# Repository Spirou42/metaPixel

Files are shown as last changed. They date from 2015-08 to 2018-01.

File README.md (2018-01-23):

# metaPixel
**A colourful open source art project.**

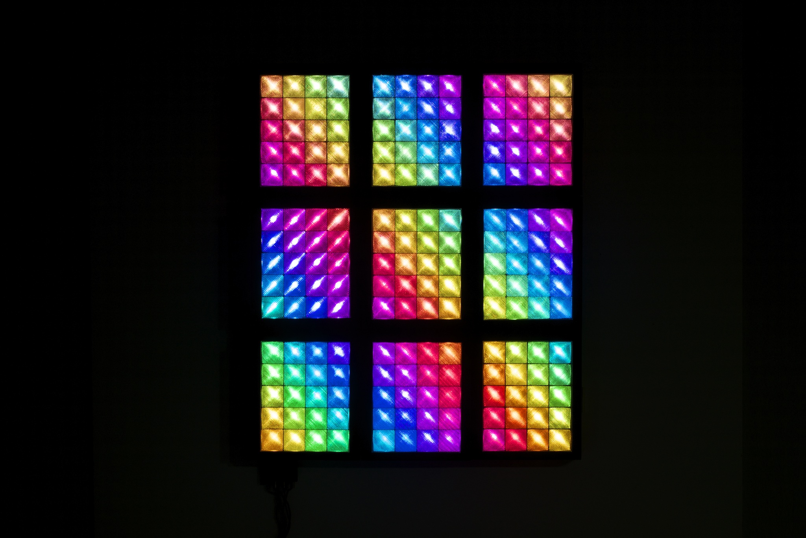
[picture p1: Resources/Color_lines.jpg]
Plasma Image


## Description
metaPixel is a (mostly) 3D printed, modular, extendable, magnetic pixel display for showing "retro" animations well known from the *good old days*™.

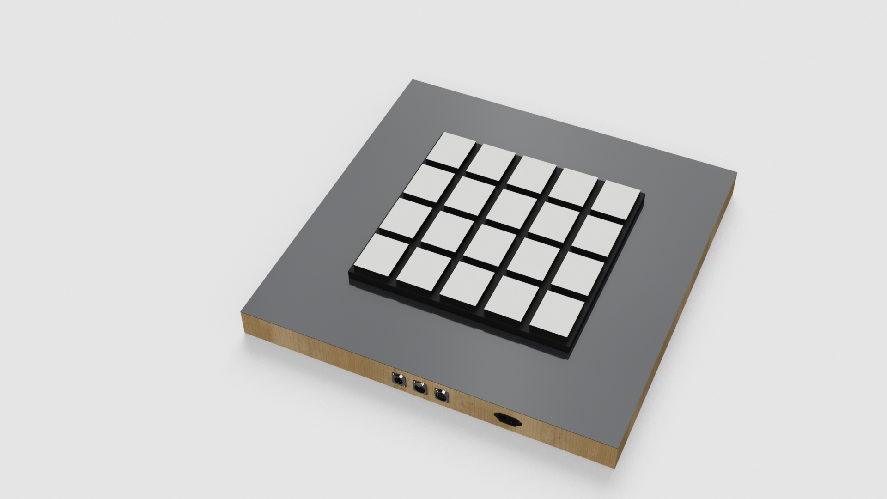
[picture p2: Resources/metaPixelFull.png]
metaPixel Design

The whole design uses a lot of magnets for adding strength to inter module connections, to hold the module cover and diffusors in place or to stick the modules onto the steel base.

The metaPixel display consists of 4 main parts:

1. steel plate
2. 20 metaPixel modules
3. controller and power supply 
4. Frame with connectors 

### Steel plate
The central structure of the whole installation is a 700 x 700 x 0.5 mm sheet of black painted steel. Both, the display modules as well as the controller and the power supply are attached with magnets to both sides of the plate.

### Frame
The steel plate is mounted to a wood frame with 20 ring magnets. 
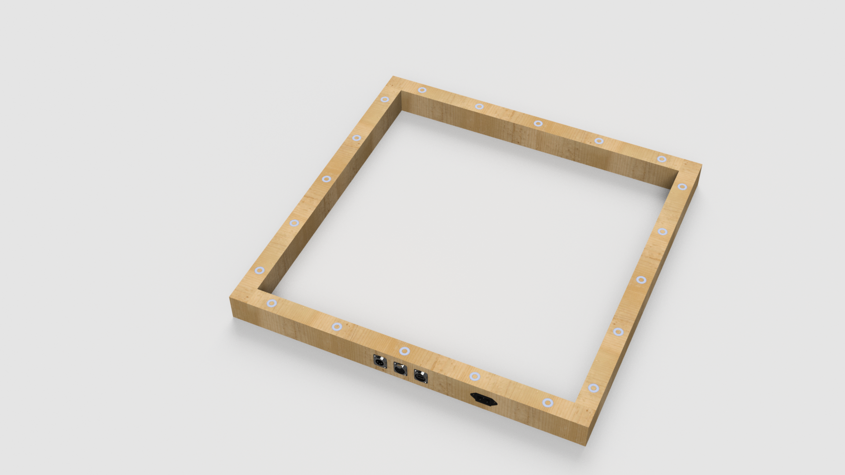
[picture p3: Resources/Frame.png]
Frame


The wood frame contains cut outs for a standard power connector as well as for DMX (3 pin XLR) and USB connectors. 
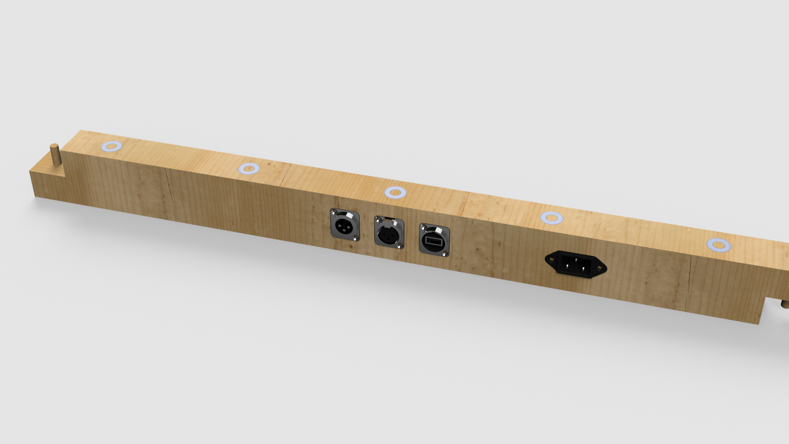
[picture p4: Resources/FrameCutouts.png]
CutOuts


### metaPixel Module
Each module contain 20 "intelligent" RGB LEDs in a 4 by 5 grid on a small printed carrier board.
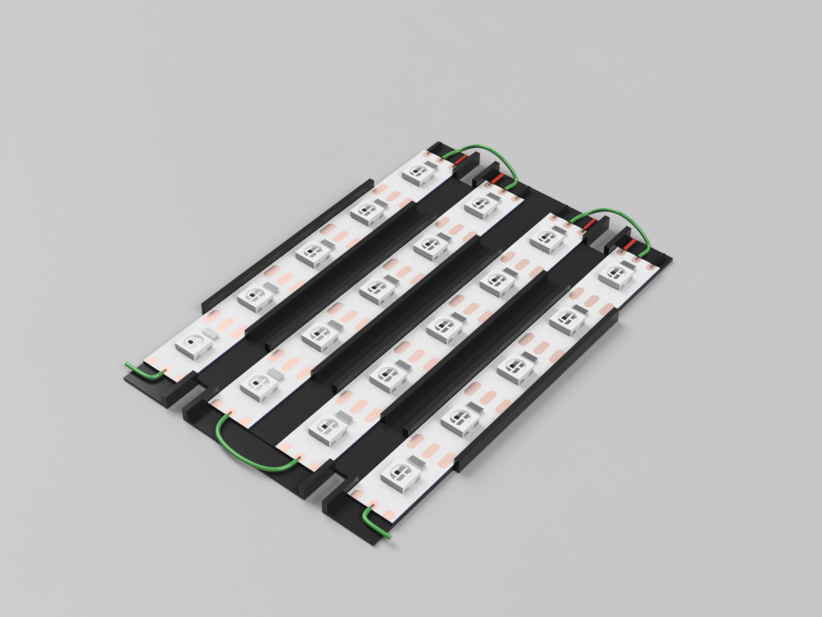
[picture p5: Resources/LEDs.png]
LED Stripes
 

The modules interconnect via a 3 pin connector. While the power connections goes straight from the input to the output with taps for each LED stripe. The data signal is routed on a zigzag path trough the stripes.
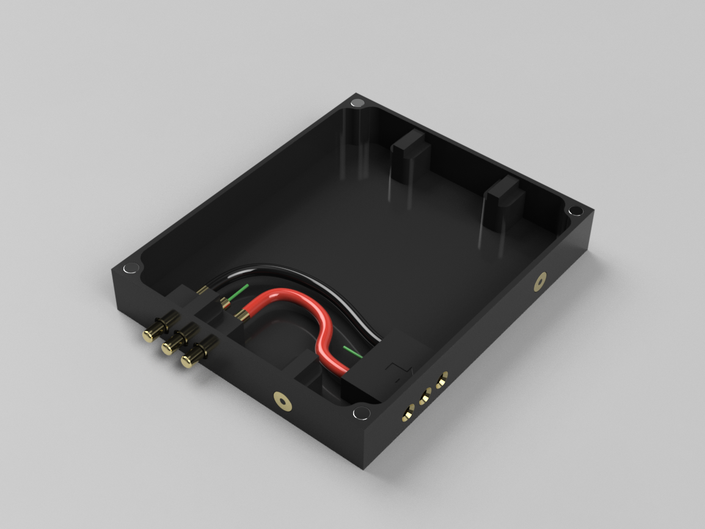
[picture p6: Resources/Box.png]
metaPixel Box


The LED carrier rests on top of four pillars which also contain some of the magnets.
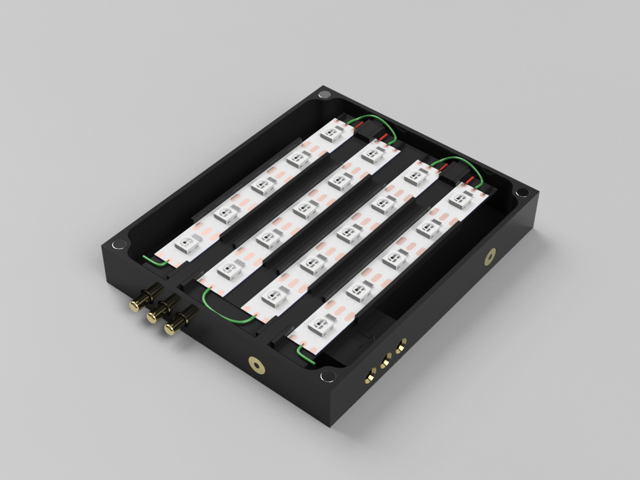
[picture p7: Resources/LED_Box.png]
metaPixel Box with LEDs


Four magnets in the corners of the box holds the cover and grid in place.
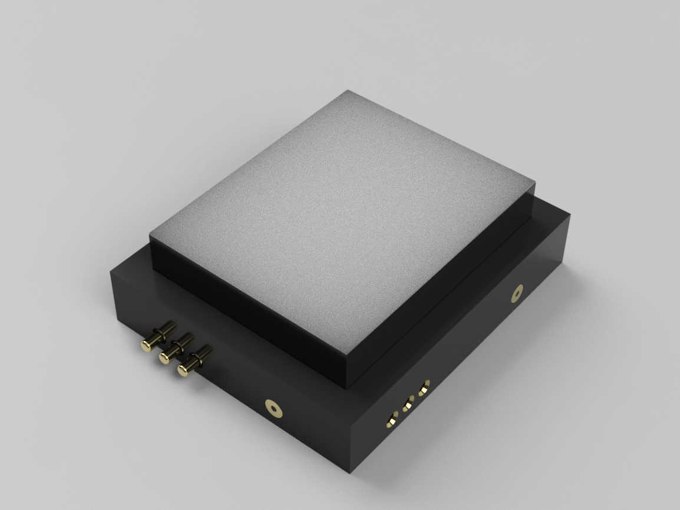
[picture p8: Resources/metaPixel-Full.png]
metaPixelWholeBox


[plasmaStripes]: Resources/Color_lines.jpg "Plasma Stripes"
[ledStripes]: Resources/LEDs.png "LED-Base"
[metaPixelBox]: Resources/Box.png "megaPixel box with connectors"
[metaPixelLedBox]: Resources/LED_BOX.png "box with LED carrier"
[metaPixelFrame]: Resources/Frame.png "Frame with connectors and magnets"
[metaPixelFrameCutOuts]: Resources/FrameCutouts.png "Frame connectors"
[metaPixelAll]: Resources/metaPixelFull.png "metaPixel Display"
[metaPixelWholeBox]: Resources/metaPixel-Full.png "a full rendered metaPixel module"
[allParts]: Resources/Components.jpg "Photo of all parts of a metaPixel"

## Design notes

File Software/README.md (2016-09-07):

#Software
Here, you'll find a basic description on how the metaPixel Software can be build and how the Software works.

## Building
The metaPixel Software uses the Arduino build environment, Teensyduino to add Teensy 3.1 support and a couple of third party libraries.

### Tools
1. [Arduino](https://www.arduino.cc/en/Main/Software) environment
2. [Teensyduino](http://www.pjrc.com/teensy/teensyduino.html)

### Libraries
1. [my version](https://github.com/Spirou42/AVRQueue) of [AVRQueue](https://github.com/Zuph/AVRQueue)  
a simple task switching library. metaPixel uses this library to implement all concurrent tasks like Backbuffer blending, Effect rendering and command execution.
2. [my version](https://github.com/Spirou42/ILI9341_t3) of [ILI9341_3](https://github.com/PaulStoffregen/ILI9341_t3) 
3. [Streaming](http://arduiniana.org/libraries/streaming/)  
C++ Stream operators for the Arduino serial class. Simply because it is easier to read and type than Arduinos `println`
4. [FastLED](http://fastled.io)  actually you have to use [my Version of FastLED](https://github.com/Spirou42/FastLED)
LED Driver Library. FastLED is a very neat LED handling library with a lot of well designed features. It supports different type of 'intelligent' LEDs and LED controllers, provides a lot of fast fixed point arithmetic and support RGB as well as HSV color space.     

## Overview
`metaPixel.h` and `metaPixel.ino` are the main files of the metaPixel controller software. `metaPixel.h` contains all definitions, prototypes, defines and includes.

###Files
* **Commands**
Serial line receiver and parser, commands, command queue and interpreter

* **Effect**
Base class for all Effects.  

* **Effect...**
The Effects itself  

* **metaDisplay**
The main class for handling the LED display. This class responsible for all display related activities like colouring pixels, drawing lines a.s.o.. In addition the `metaDisplay` class ist

* **metaModule**
A coordinate mapper for a single module used by `metaDisplay` to map `(x,y)` coordinates to a frame buffer index.

* **Palettes**
A couple of Palette definitions extracted with FastLEDs [PaletteKnife](http://fastled.io/tools/paletteknife/) tool from [cpt-city](http://soliton.vm.bytemark.co.uk/pub/cpt-city/)

* **Parameter**
A couple of interrupt changeable, animatable `int16_t` values. This class provides the basic infrastructure for managing and mapping parameters.

* **Types**
The content of this file will move to different places in the future. Actually it contains bunch of structure and type definitions.

* **VT100Stream**
Some extensions for streaming VT100 control chars.

## Controlling the Display

metaPixel is a simple state machine controlled by a couple of `int16_t` values encapsulated into a `Parameter16_t` class providing simple animation capabilities.

Fifteen `Parameter16_t` values are actually implemented and used to control global and effect local functions.

<table>
<tr><th>Index</th><th>Parameter Name</th><th>Range</th><th>Description</th></tr>
<tr><th colspan='4' align='left'>System Parameter</th></tr>
<tr><td align="center">0</td><td align="center">P</td><td align="center">0 - 6</td><td>Effect Program</td></tr>
<tr><td align="center">1</td><td align="center">D</td><td align="center">1 - 5000</td><td>Effect Frame Delay</td></tr>
<tr><td align="center">2</td><td align="center">C</td><td align="center">0 - 11</td><td>Palette</td></tr>
<tr><td align="center">3</td><td align="center">B</td><td align="center">0 - 255</td><td>LED Brightness</td></tr>
<tr><td align="center">4</td><td align="center">Q</td><td align="center">0 - 5</td><td>Mirror Mode</td></tr>
<tr><td align="center">5</td><td align="center">Z</td><td align="center">1 - 14</td><td>Blend factor</td></tr>
<tr><td align="center">6</td><td align="center">A</td><td align="center">0 - 1</td><td>Display Resoultion</td></tr>
<tr><th colspan='4' align='left'>Effect Parameter</th></tr>
<tr><td align="center">7</td> <td align="center">U</td><td align="center">-</td><td>Effect Speed 1</td></tr>
<tr><td align="center">8</td> <td align="center">V</td><td align="center">-</td><td>Effect Speed 1</td></tr>
<tr><td align="center">9</td> <td align="center">R</td><td align="center">-</td><td>Effect Scale 1</td></tr>
<tr><td align="center">10</td><td align="center">I</td><td align="center">-</td><td>Effect Scale 2</td></tr>
<tr><td align="center">11</td><td align="center">O</td><td align="center">-</td><td>Effect Parameter 1</td></tr>
<tr><td align="center">12</td><td align="center">H</td><td align="center">-</td><td>Effect Parameter 1</td></tr>
<tr><td align="center">13</td><td align="center">M</td><td align="center">0 - 255</td><td>Effect Mask 1</td></tr>
<tr><td align="center">14</td><td align="center">N</td><td align="center">0 - 255</td><td>Effect Mask 2</td></tr>
</table>

### Serial Interface
The metaPixel display is controlled by a simple serial command line interface. Connect your computer to the USB-Serial with a VT100 capable terminal program and press `Return`

	Effect: Noise
	Parameter:
	nScale    [R] 35 (255)        nSpeed    [U]*5 (255)         hSpeed    [V] 253 (255)
	nMask     [M] 1 (7)

	Program   [P] 1 (6)           Delay     [D] 100 (5000)      Palette   [C] 8 (11)
	Bright    [B] 160 (255)       Mirror    [Q] 0 (5)           Fade      [Z] 3 (14)
	Res       [A] 1 (1)

	>

From top to bottom you'll see:
* the name of the currently running Effect
* the effect parameters
* the system parameters

Each parameter entry consist of 5 parts
1. Descriptive Name
2. Parameter Name in `[]`
3. current value
4. optional animation marker `*`
5. current max value in `()`

To change a value simply type the parameter name followed by the new value. For example sending `P5` or `p5` will change the current effect to **Fire**
You can combine as many value changes in a single line as you wish as long as the line length did not exceed 512 bytes.

#### Additional Commands
In addition setting a single value to a effect parameter there is a couple of 'control' commands implemented.

<table>
<tr><th>Function</th><th>Command</th><th>Format</th></tr>
<tr><td>Bounce</td><td>~</td><td>~[paraName][startValue] [endValue] [time]</td></tr>
<tr><td colspan=2></td><td >Bounces the value of [paraName] between [startValue] and [endValue] in [time] sec.</td></tr>
<tr><td>Animate</td><td>@</td><td>@[paraName][startValue] [endValue] [time]</td></tr>
<tr><td colspan=2></td><td>Animates the value of [paraName] from [startValue] to [endValue] in [time] sec.</td></tr>
<tr><td>Stop Animate</td><td>*</td><td>*[paraName]</td></tr>
<tr><td colspan=2></td><td>Stops any animation on parameter [paraName]</td></tr>
<tr><td>Wait</td><td>&</td><td>&[time]</td></tr>
<tr><td colspan=2></td><td>Stops command processing for [time] sec.</td></tr>
<tr><td>Wait for Animation</td><td>%</td><td>%[paraName]</td></tr>
<tr><td colspan=2></td><td>Stops command processing until animation is finished. If Bounce is enabled on [paraName] this command will wait until the next limit (up or down) is reached.</td></tr>
<tr><td>Dump</td><td>?</td><td>?</td></tr>
<tr><td colspan=2></td><td>dumps the current parameter set as a command line.</td></tr>
<tr><td>Macro</td><td>#</td><td>#[macroNumber]</td></tr>
<tr><td colspan=2></td><td>call the hard coded macro with the given number. Macros are simple hard coded strings containing a bunch of parameter changes and commands to control a effect sequence. It is allowed to build circular references.</td></tr>

</table>

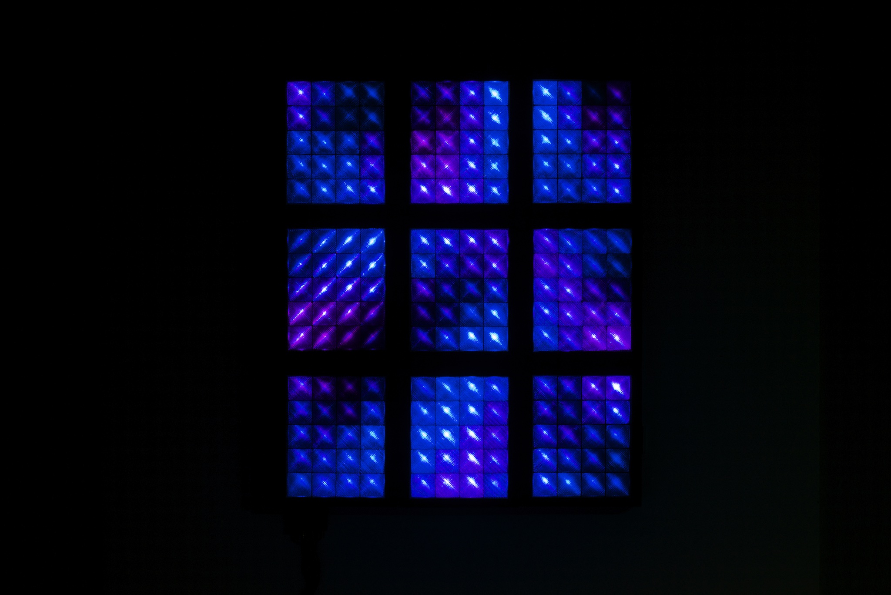
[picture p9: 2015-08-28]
Resources/Noise.jpg

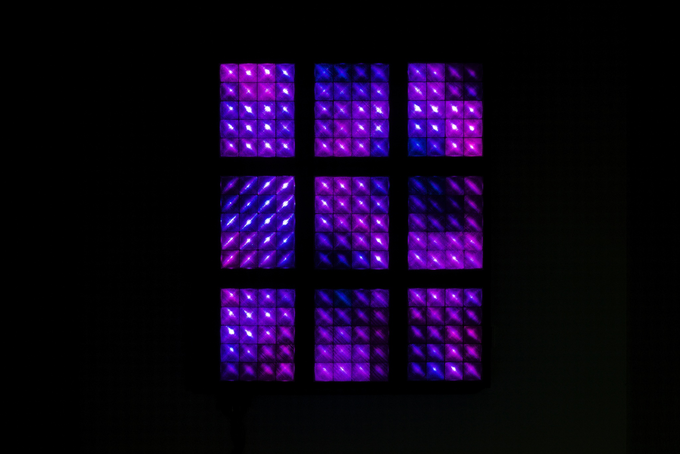
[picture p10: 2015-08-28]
Resources/Noise_(1).jpg

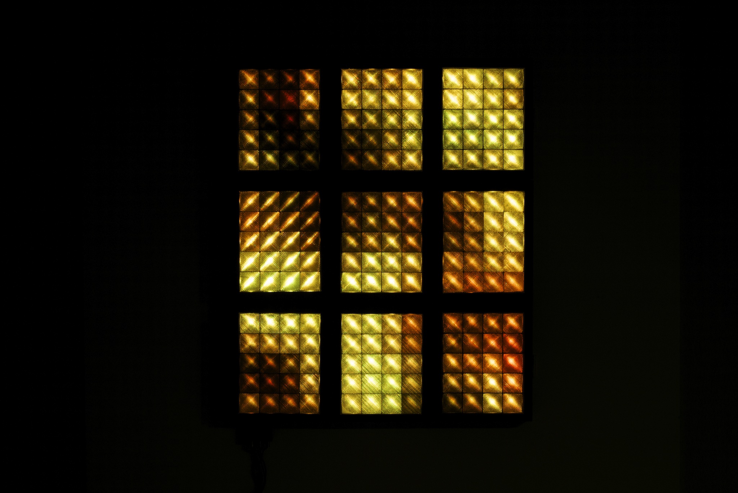
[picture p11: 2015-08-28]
Resources/Noise_(2).jpg

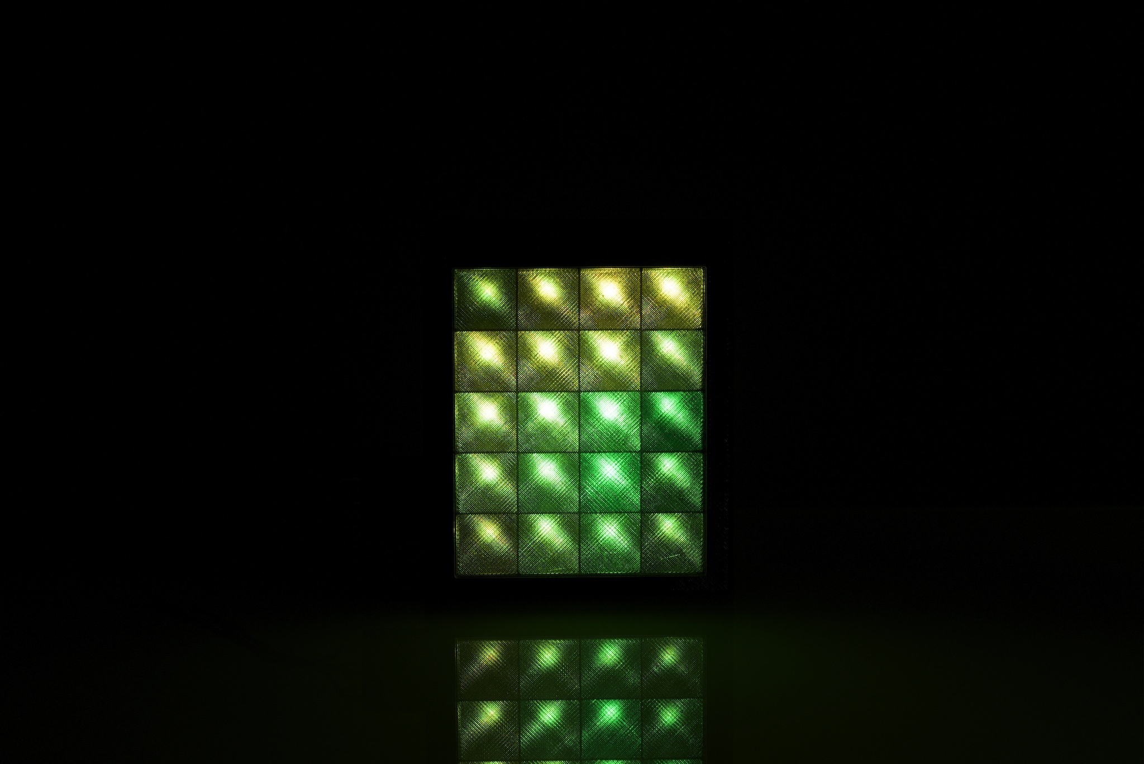
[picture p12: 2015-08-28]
Resources/lightshow_(3).jpg

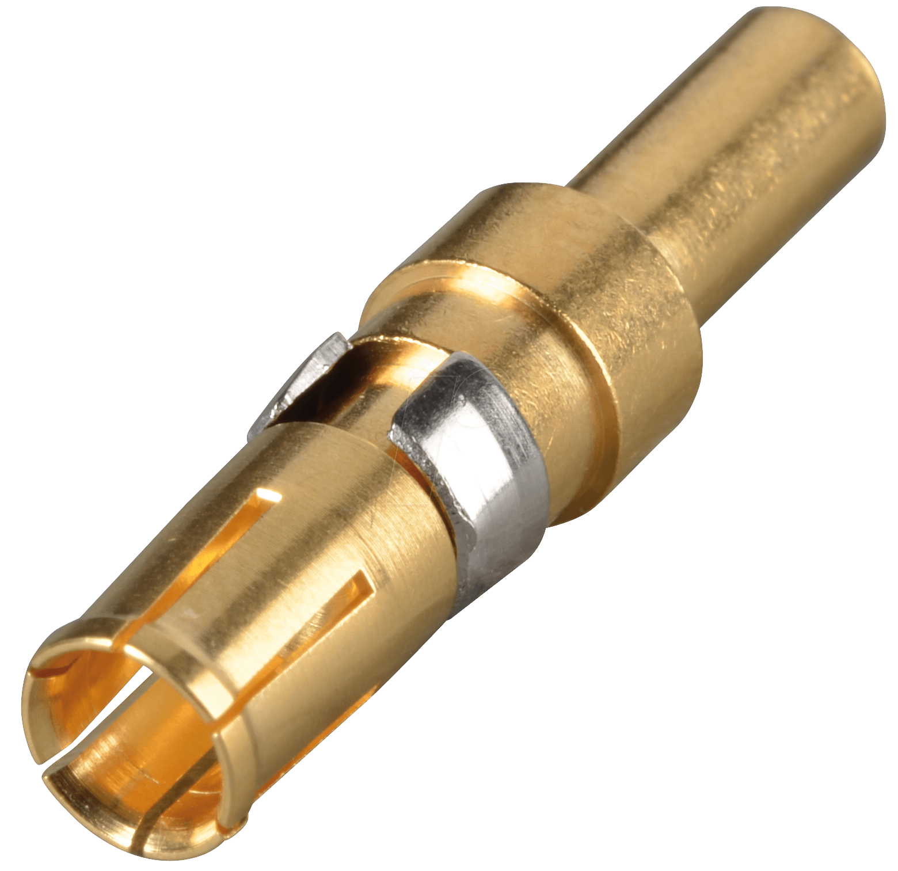
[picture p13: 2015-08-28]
Resources/BUCRIMP3.png

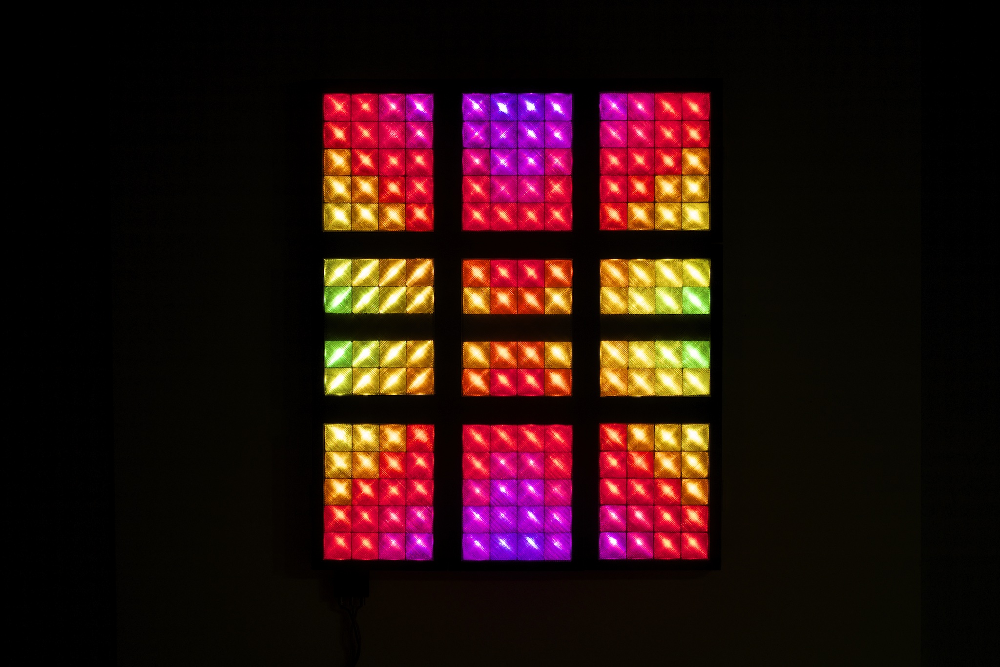
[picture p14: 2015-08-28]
Resources/Color_lines_(1).jpg

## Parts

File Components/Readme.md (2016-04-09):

# Components
here you find all the cad files for creating your own metaPixel display.
## Files

* STL
All essential files, ready for slicing.
	* BOX-(BL|BR|TL|TR|MC).stl
	5 different box configurations. 4 corners **T**op**L**eft, **B**ottom**L**eft, **B**ottom**R**ight and **T**op**R**ight and one module going in between (**MC**).  
	
	* Cover.stl
	The cover frame, you need one for each box.
	
	* Grid.stl
	a single grid.
	
	* DiffusorFoil.stl
	The printable diffusor. You have to play around with under/over extrusion to find an effect thats suits your 
	
	* DiffusorGrid.stl
	The grid and the diffusor as a single body. Incase you prefer a less saturated display.
	
	* LedBase.stl
	The base for gluing the led stripe on. 

* CAD
Contains CAD source files for the more curios. You'll find STEP, IGES and [Fusion360](http://fusion360.autodesk.com)Archives
	* metaPixel.(STEP|IGES|f3d)
	a Template for creating your own boxes or connections.

	* metaPixel-Boxes.(STEP|IGES|f3d)
	all the box configurations for my metaPixel display.

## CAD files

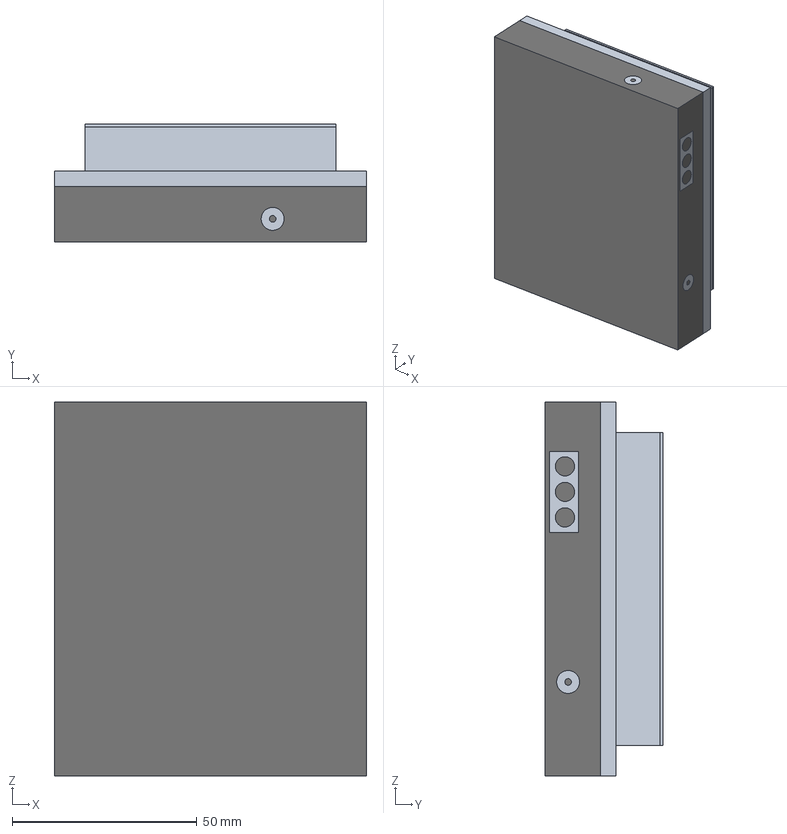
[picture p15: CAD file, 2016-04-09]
Components/CAD/metaPixel.step
84.4 x 31.8 x 101.1 mm
DiffusorGrid v3
DiskMagnet v1
Conec_3Pin-MaleIn v1
Conec_3Pin-FemaleOut v2 v1
Cover
LedBase New
Diffusor

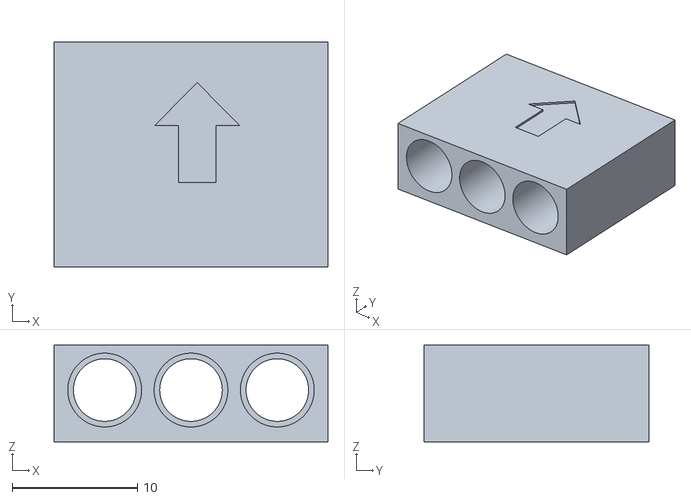
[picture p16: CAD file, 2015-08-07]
Components/STL/Connector.stl
21.9 x 18.0 x 7.75

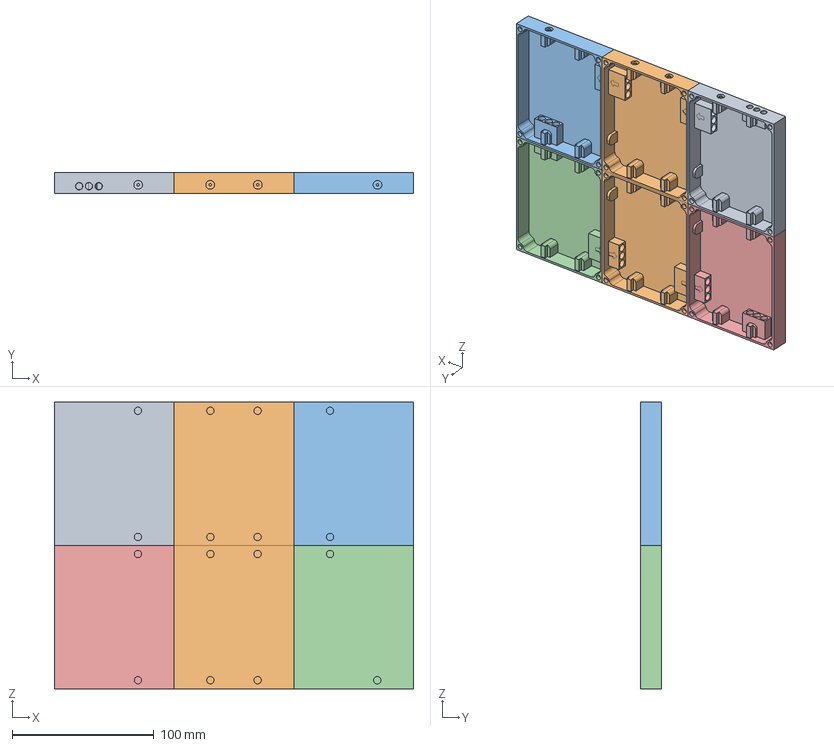
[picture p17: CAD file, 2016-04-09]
Components/CAD/metaPixel-Boxes.step
253.3 x 15.0 x 202.2 mm
Box BL
Box MC x 2
Box BR
Box TR
Box TL

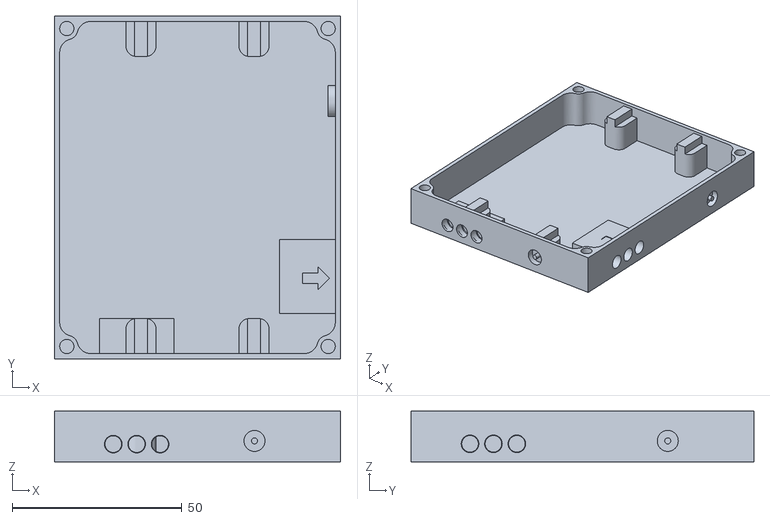
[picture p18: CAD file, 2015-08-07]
Components/STL/Box-BL.stl
84.4 x 101.1 x 15.0

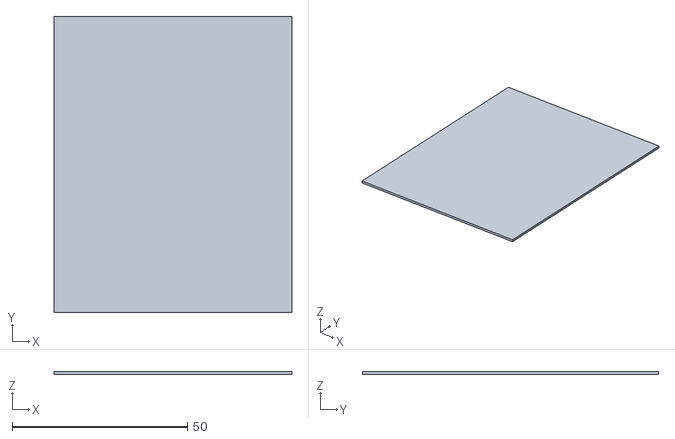
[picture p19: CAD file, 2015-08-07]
Components/STL/DiffusorFoil.stl
67.8 x 84.5 x 0.8

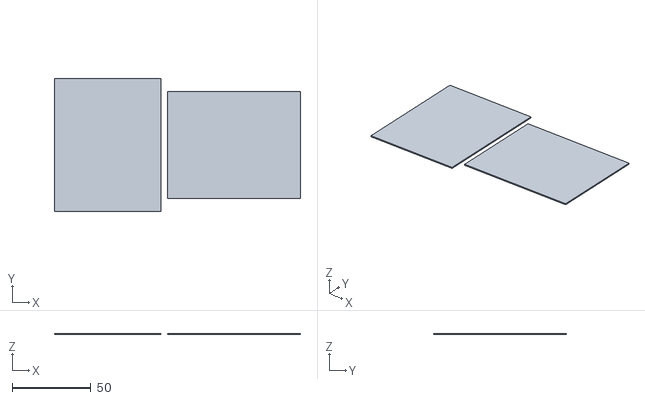
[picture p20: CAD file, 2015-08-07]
Components/STL/DiffusorFoil 08-2.stl
156.3 x 84.5 x 0.8

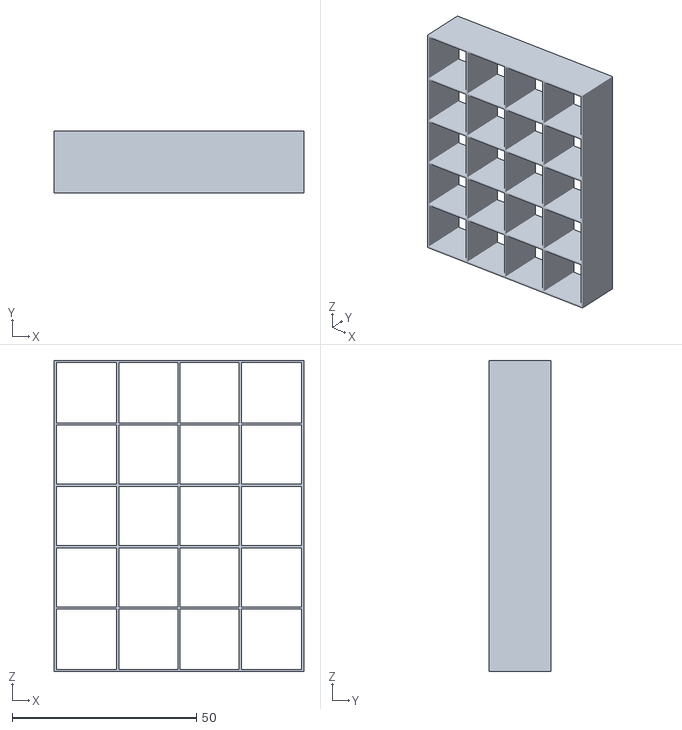
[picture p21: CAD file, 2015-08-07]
Components/STL/Grid.stl
67.8 x 16.8 x 84.5

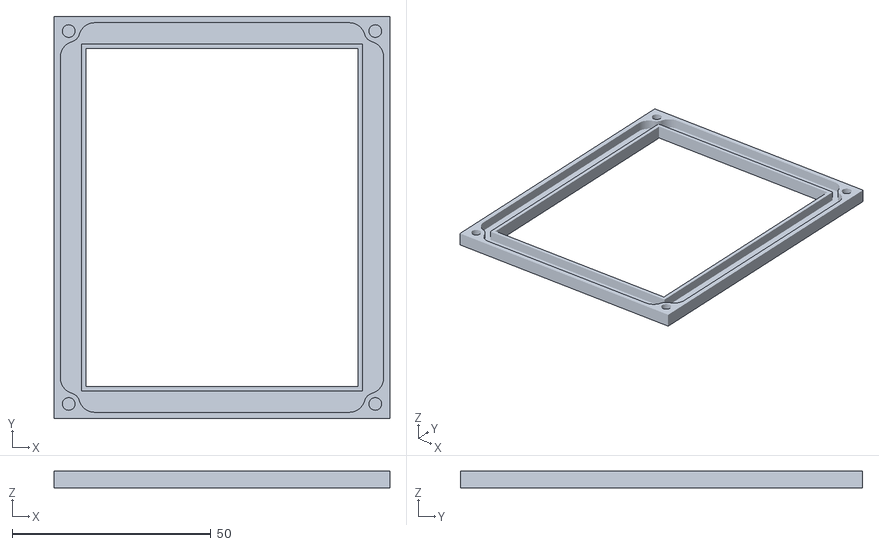
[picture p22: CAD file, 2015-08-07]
Components/STL/Cover.stl
84.4 x 101.1 x 4.20

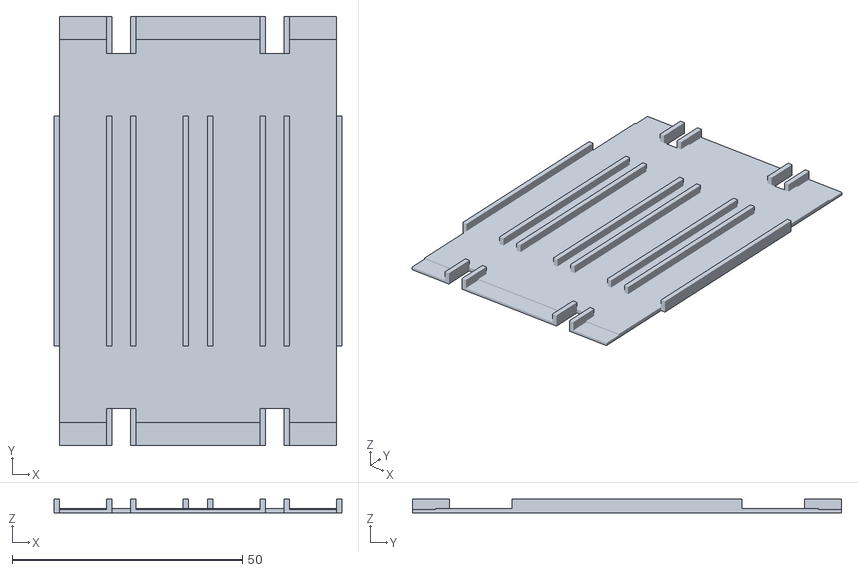
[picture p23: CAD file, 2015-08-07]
Components/STL/LedBase.stl
62.6 x 93.3 x 3.00

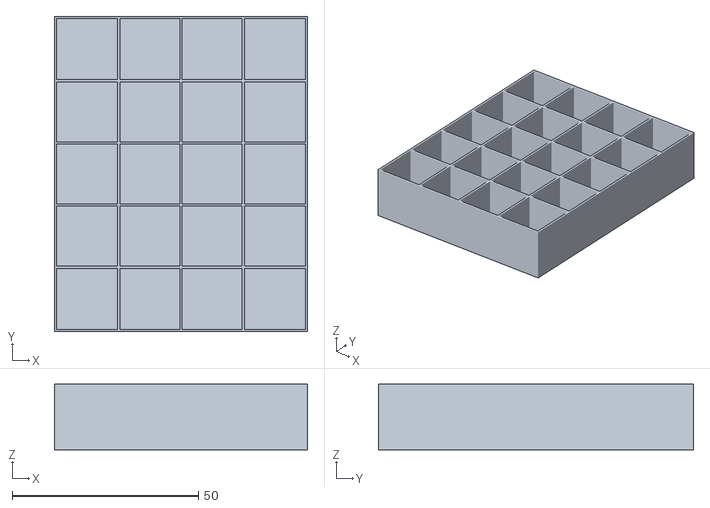
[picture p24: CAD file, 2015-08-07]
Components/STL/DiffusorGrid.stl
67.8 x 84.5 x 17.6

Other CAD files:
Components/STL/Box-TR.stl
Components/STL/Box-TL.stl
Components/STL/Box-BR.stl
Components/STL/Box-MC.stl
Components/CAD/metaPixel-Boxes v28.f3d
Components/CAD/metaPixel-Boxes.f3d
Components/CAD/metaPixel-Boxes.iges
Components/CAD/metaPixel.f3d
Components/CAD/metaPixel.iges

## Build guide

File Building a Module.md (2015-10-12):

##Building a metaPixel module
###Material
1.

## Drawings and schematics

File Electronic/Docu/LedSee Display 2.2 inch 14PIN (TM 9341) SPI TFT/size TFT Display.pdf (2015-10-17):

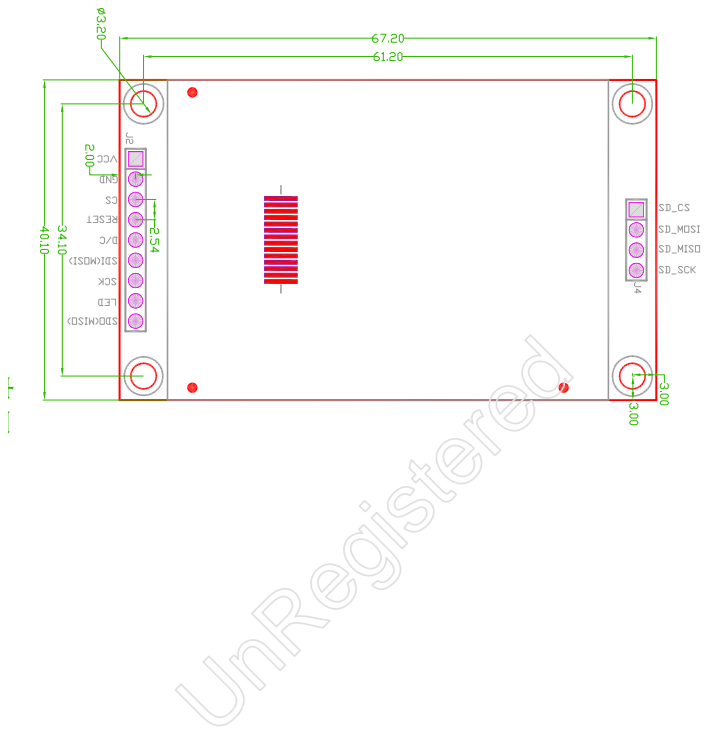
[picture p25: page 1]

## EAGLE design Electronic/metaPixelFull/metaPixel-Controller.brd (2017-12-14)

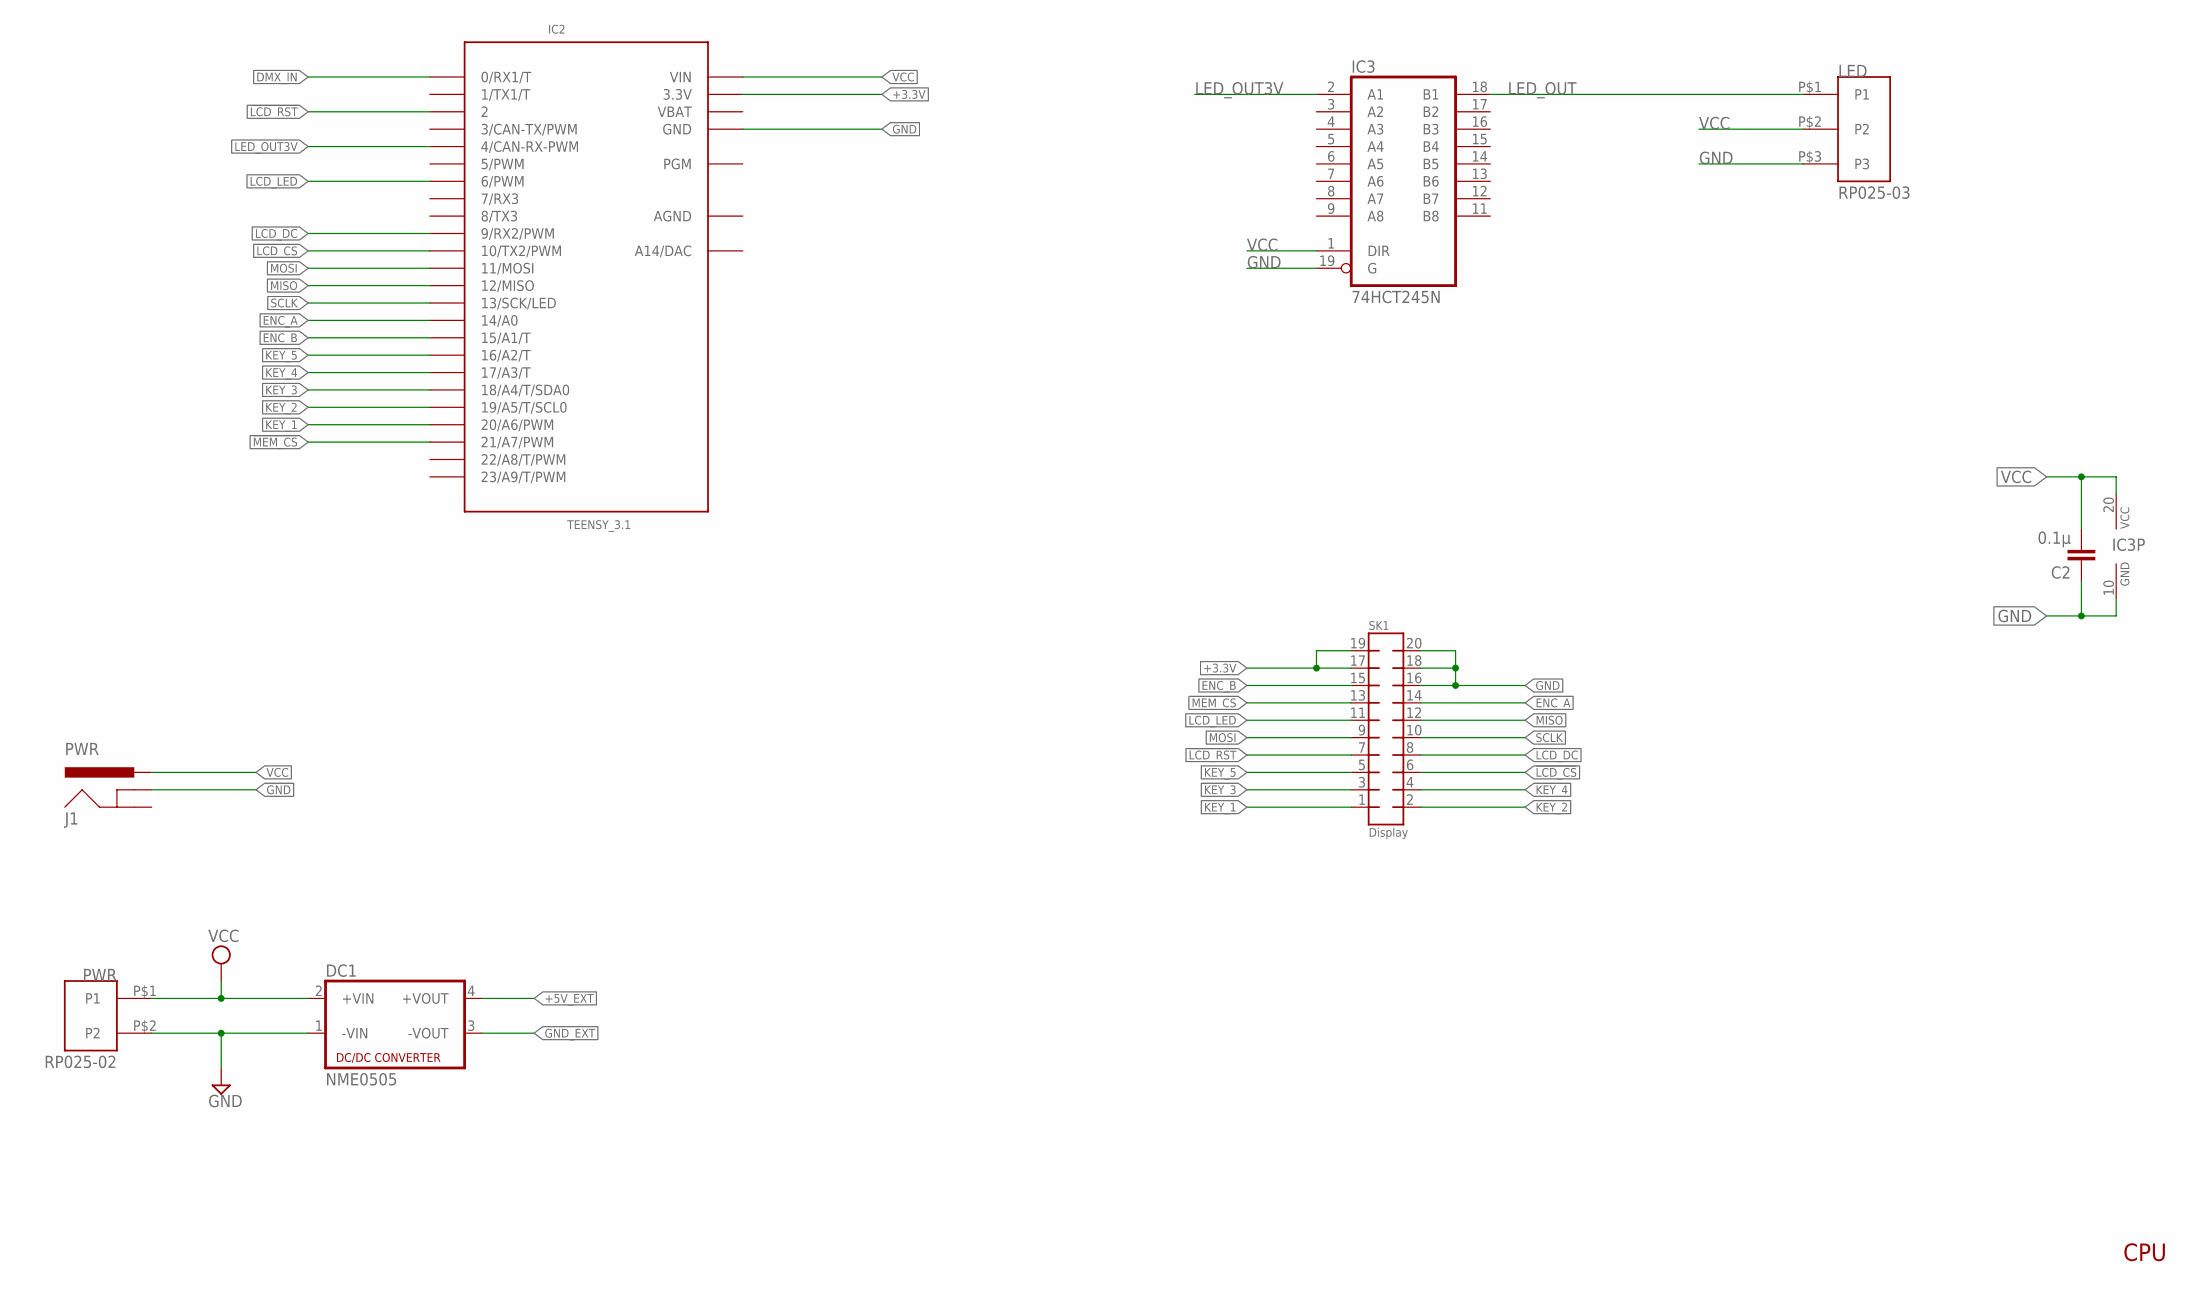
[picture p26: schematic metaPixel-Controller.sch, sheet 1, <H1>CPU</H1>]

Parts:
C2: 0.1µ; C025-030X050
DC1: NME0505; NME
IC2: TEENSY_3.1; TEENSY3-OUTER_ROW
IC3: 74HCT245N; DIL20
J1: PWR; POWER_JACK_SLOT
LED: RP025-03
PWR: RP025-02
SK1: Display; AMP-215079-20

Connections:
!LCD_CS: IC2.10 (10/TX2/PWM), SK1.6
!LCD_RST: IC2.2, SK1.7
!MEM_CS: IC2.21/A7 (21/A7/PWM), SK1.13
+3.3V: IC2.3.3V, IC2.3.3V1 (3.3V), SK1.17, SK1.19
+5V_EXT: DC1.4 (+VOUT); also elsewhere on the board
AGND: IC2.AGND
DMX_IN: IC2.0 (0/RX1/T); also elsewhere on the board
ENC_A: IC2.14/A0, SK1.14
ENC_B: IC2.15/A1 (15/A1/T), SK1.15
GND: C2.1, DC1.1 (-VIN), IC2.GND, IC2.GND1 (GND), IC3.10 (GND), IC3.19 (G), J1.GND@1 (GNDBREAK), LED.P$3 (P3), PWR.P$2 (P2), SK1.16, SK1.18, SK1.20; also elsewhere on the board
GND_EXT: DC1.3 (-VOUT); also elsewhere on the board
KEY_1: IC2.20/A6 (20/A6/PWM), SK1.1
KEY_2: IC2.19/A5 (19/A5/T/SCL0), SK1.2
KEY_3: IC2.18/A4 (18/A4/T/SDA0), SK1.3
KEY_4: IC2.17/A3 (17/A3/T), SK1.4
KEY_5: IC2.16/A2 (16/A2/T), SK1.5
LCD_DC: IC2.9 (9/RX2/PWM), SK1.8
LCD_LED: IC2.6 (6/PWM), SK1.11
LED_OUT: IC3.18 (B1), LED.P$1 (P1)
LED_OUT3V: IC2.4 (4/CAN-RX-PWM), IC3.2 (A1)
MISO: IC2.12 (12/MISO), SK1.12
MOSI: IC2.11 (11/MOSI), SK1.9
SCLK: IC2.13 (13/SCK/LED), SK1.10
VBAT: IC2.VBAT
VCC: C2.2, DC1.2 (+VIN), IC2.VIN, IC3.1 (DIR), IC3.20 (VCC), J1.PWR, LED.P$2 (P2), PWR.P$1 (P1); also elsewhere on the board

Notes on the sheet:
CPU

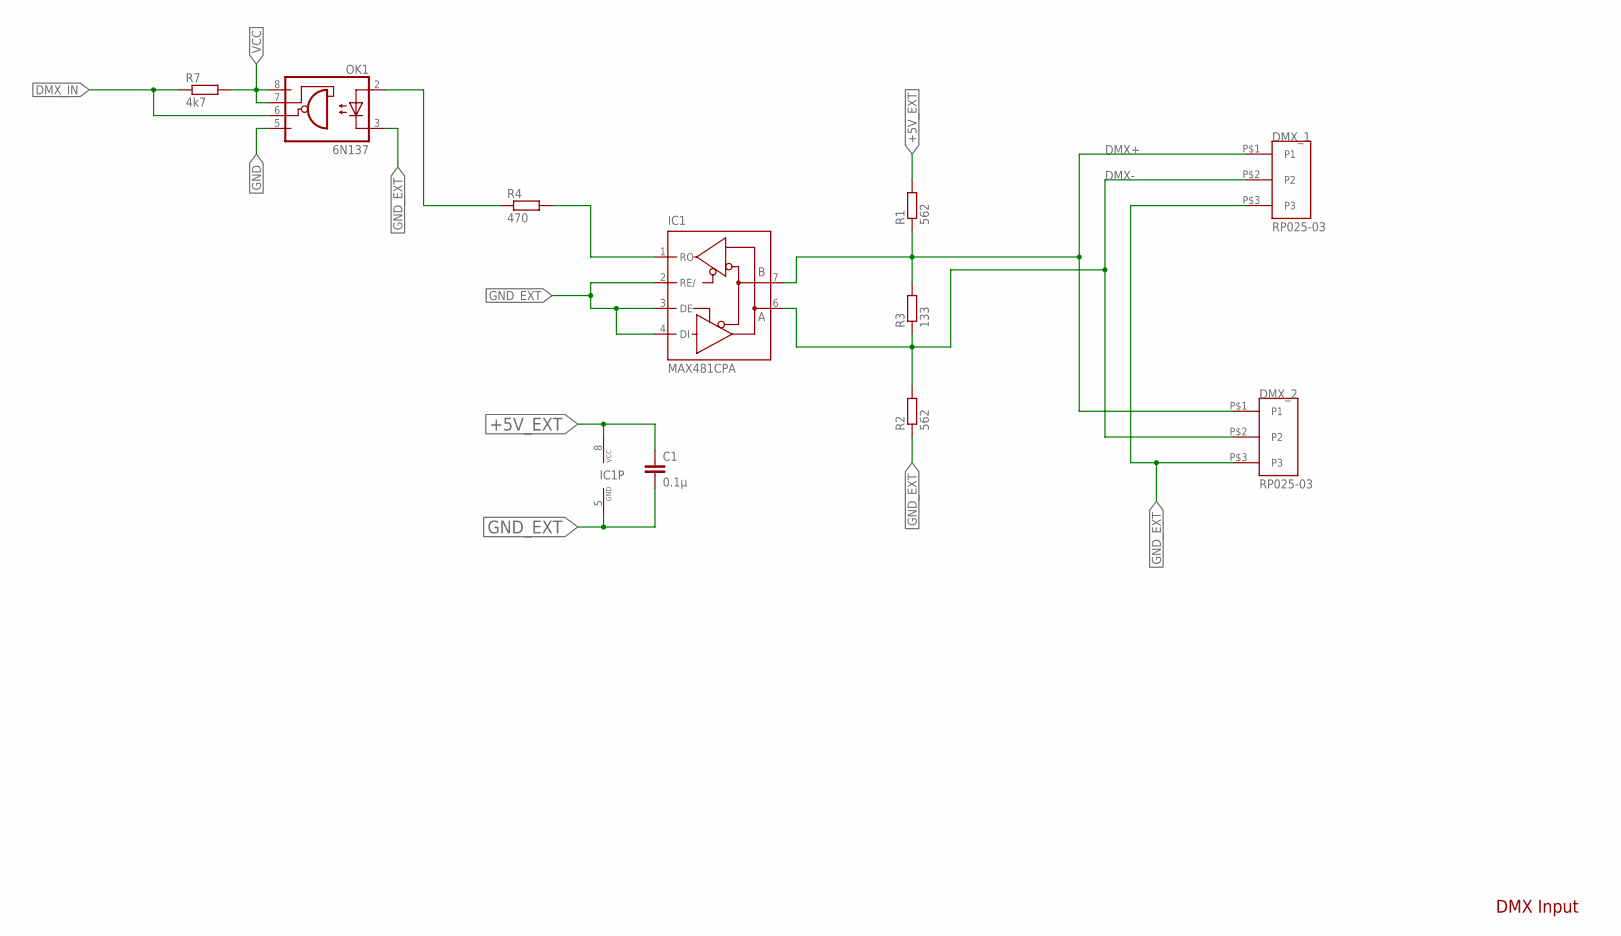
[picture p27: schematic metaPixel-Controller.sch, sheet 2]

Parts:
C1: 0.1µ; C025-030X050
DMX_1, DMX_2: RP025-03
IC1: MAX481CPA; DIL08
OK1: 6N137; DIL08
R1, R2: 562; 0207/7
R3: 133; 0207/7
R4: 470; 0207/10
R7: 4k7; 0207/10

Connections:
+5V_EXT: C1.1, IC1.8 (VCC), R1.2; also elsewhere on the board
DMX+: DMX_1.P$1 (P1), DMX_2.P$1 (P1), IC1.7 (B), R1.1, R3.2
DMX-: DMX_1.P$2 (P2), DMX_2.P$2 (P2), IC1.6 (A), R2.2, R3.1
DMX_IN: OK1.6 (VO), R7.1; also elsewhere on the board
GND: OK1.5 (GND); also elsewhere on the board
GND_EXT: C1.2, DMX_1.P$3 (P3), DMX_2.P$3 (P3), IC1.2 (RE/), IC1.3 (DE), IC1.4 (DI), IC1.5 (GND), OK1.3 (C), R2.1; also elsewhere on the board
unnamed: OK1.2 (A), R4.1
unnamed: IC1.1 (RO), R4.2
VCC: OK1.7 (VE), OK1.8 (VCC), R7.2; also elsewhere on the board

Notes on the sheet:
DMX Input

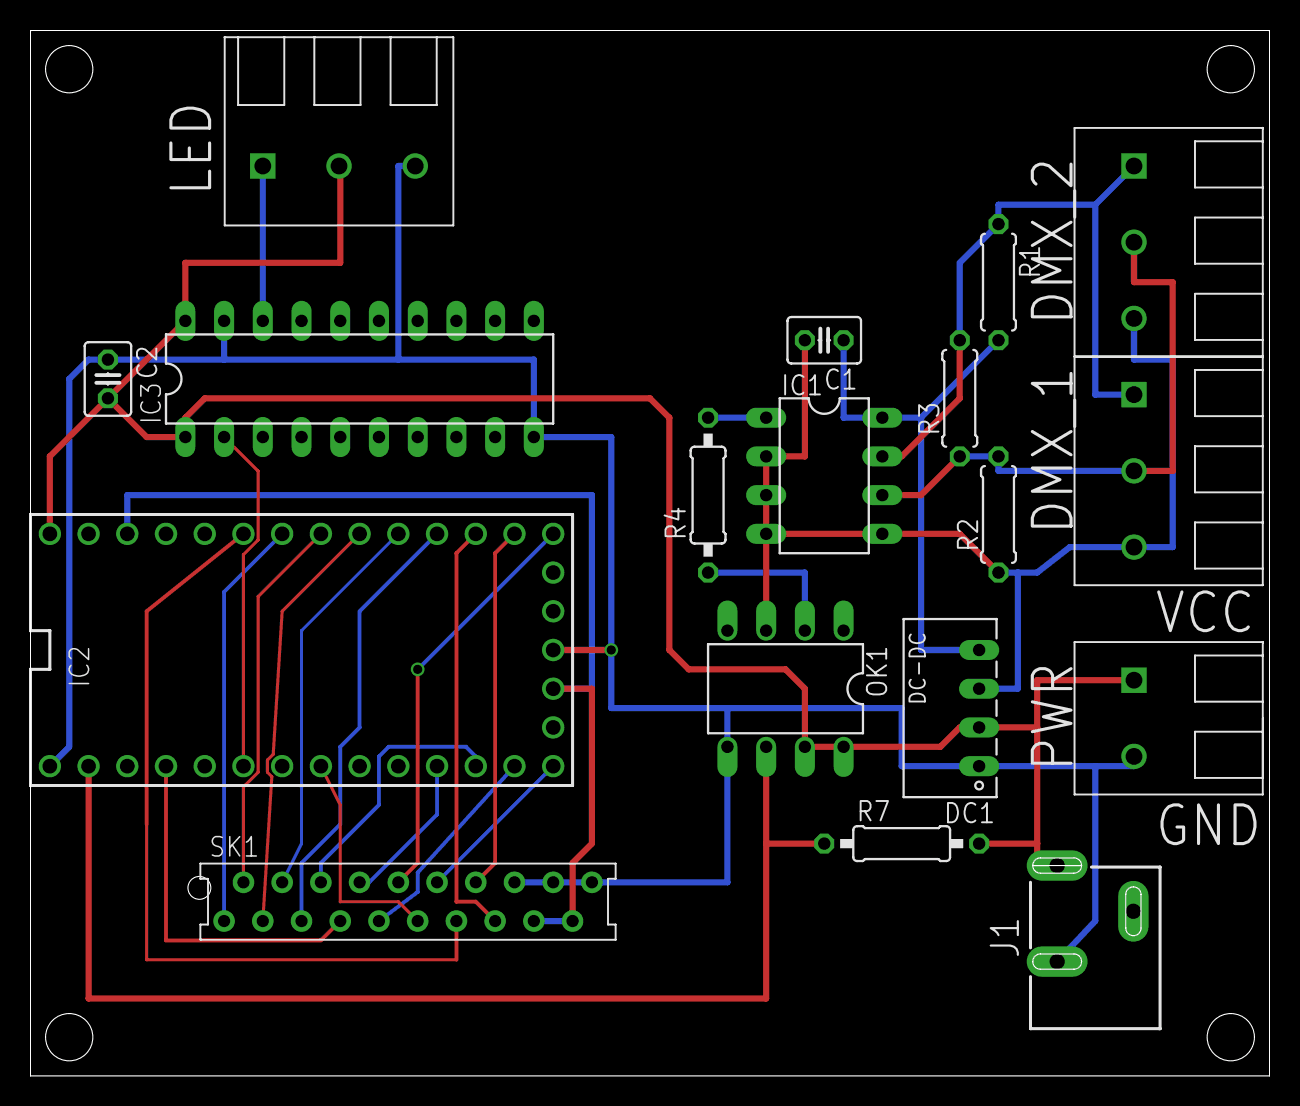
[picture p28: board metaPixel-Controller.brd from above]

Board: 2 copper layers, 81.3 x 68.6 mm, 18 parts (0 on the bottom side), 27 nets.

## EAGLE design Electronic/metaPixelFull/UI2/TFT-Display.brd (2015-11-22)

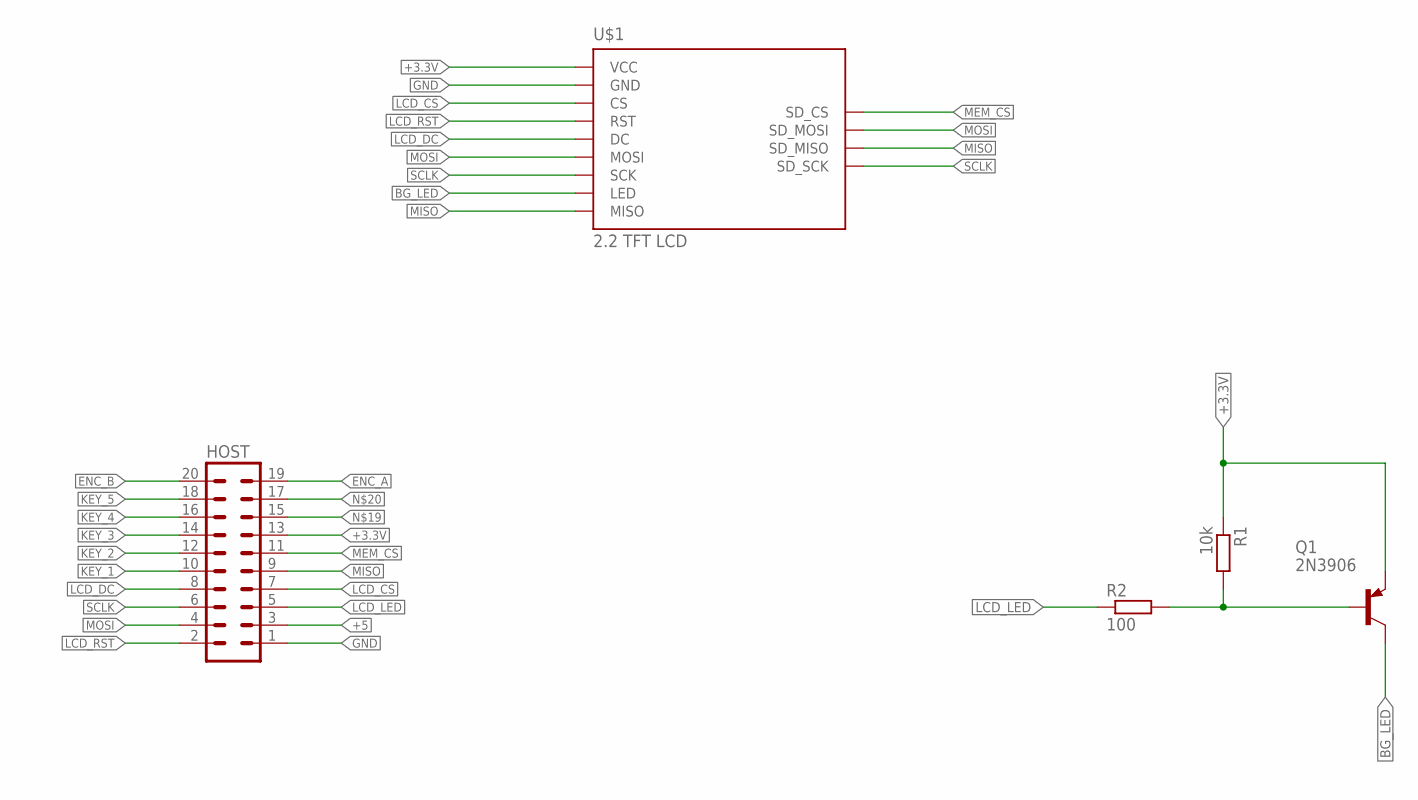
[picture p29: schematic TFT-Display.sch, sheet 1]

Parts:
HOST: ML20L
Q1: 2N3906; TO92
R1: 10k; 0204/7
R2: 100; 0204/7
U$1: 2.2_TFT_LCDNEW; 2.2_TFT_LCD_LEDSEE

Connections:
!LCD_CS: HOST.7, U$1.P$3_CS (CS)
!LCD_RST: HOST.2, U$1.P$2_RESET (RST)
!MEM_CS: HOST.11, U$1.P$2_SD_CS (SD_CS)
+3.3V: HOST.13, Q1.3 (E), R1.1, U$1.P$5_VCC (VCC); also elsewhere on the board
+5: HOST.3
BG_LED: Q1.1 (C), U$1.P$8_LED (LED)
ENC_A: HOST.19; also elsewhere on the board
ENC_B: HOST.20; also elsewhere on the board
GND: HOST.1, U$1.P$4_GND (GND); also elsewhere on the board
KEY_1: HOST.10; also elsewhere on the board
KEY_2: HOST.12; also elsewhere on the board
KEY_3: HOST.14; also elsewhere on the board
KEY_4: HOST.16; also elsewhere on the board
KEY_5: HOST.18; also elsewhere on the board
LCD_DC: HOST.8, U$1.P$1_DC (DC)
LCD_LED: HOST.5, R2.1
MISO: HOST.9, U$1.P$3_SD_MISO (SD_MISO), U$1.P$9_MISO (MISO)
MOSI: HOST.4, U$1.P$1_SD_MOSI (SD_MOSI), U$1.P$6_MOSI (MOSI)
unnamed: Q1.2 (B), R1.2, R2.2
SCLK: HOST.6, U$1.P$4_SD_SCK (SD_SCK), U$1.P$7_SCK (SCK)

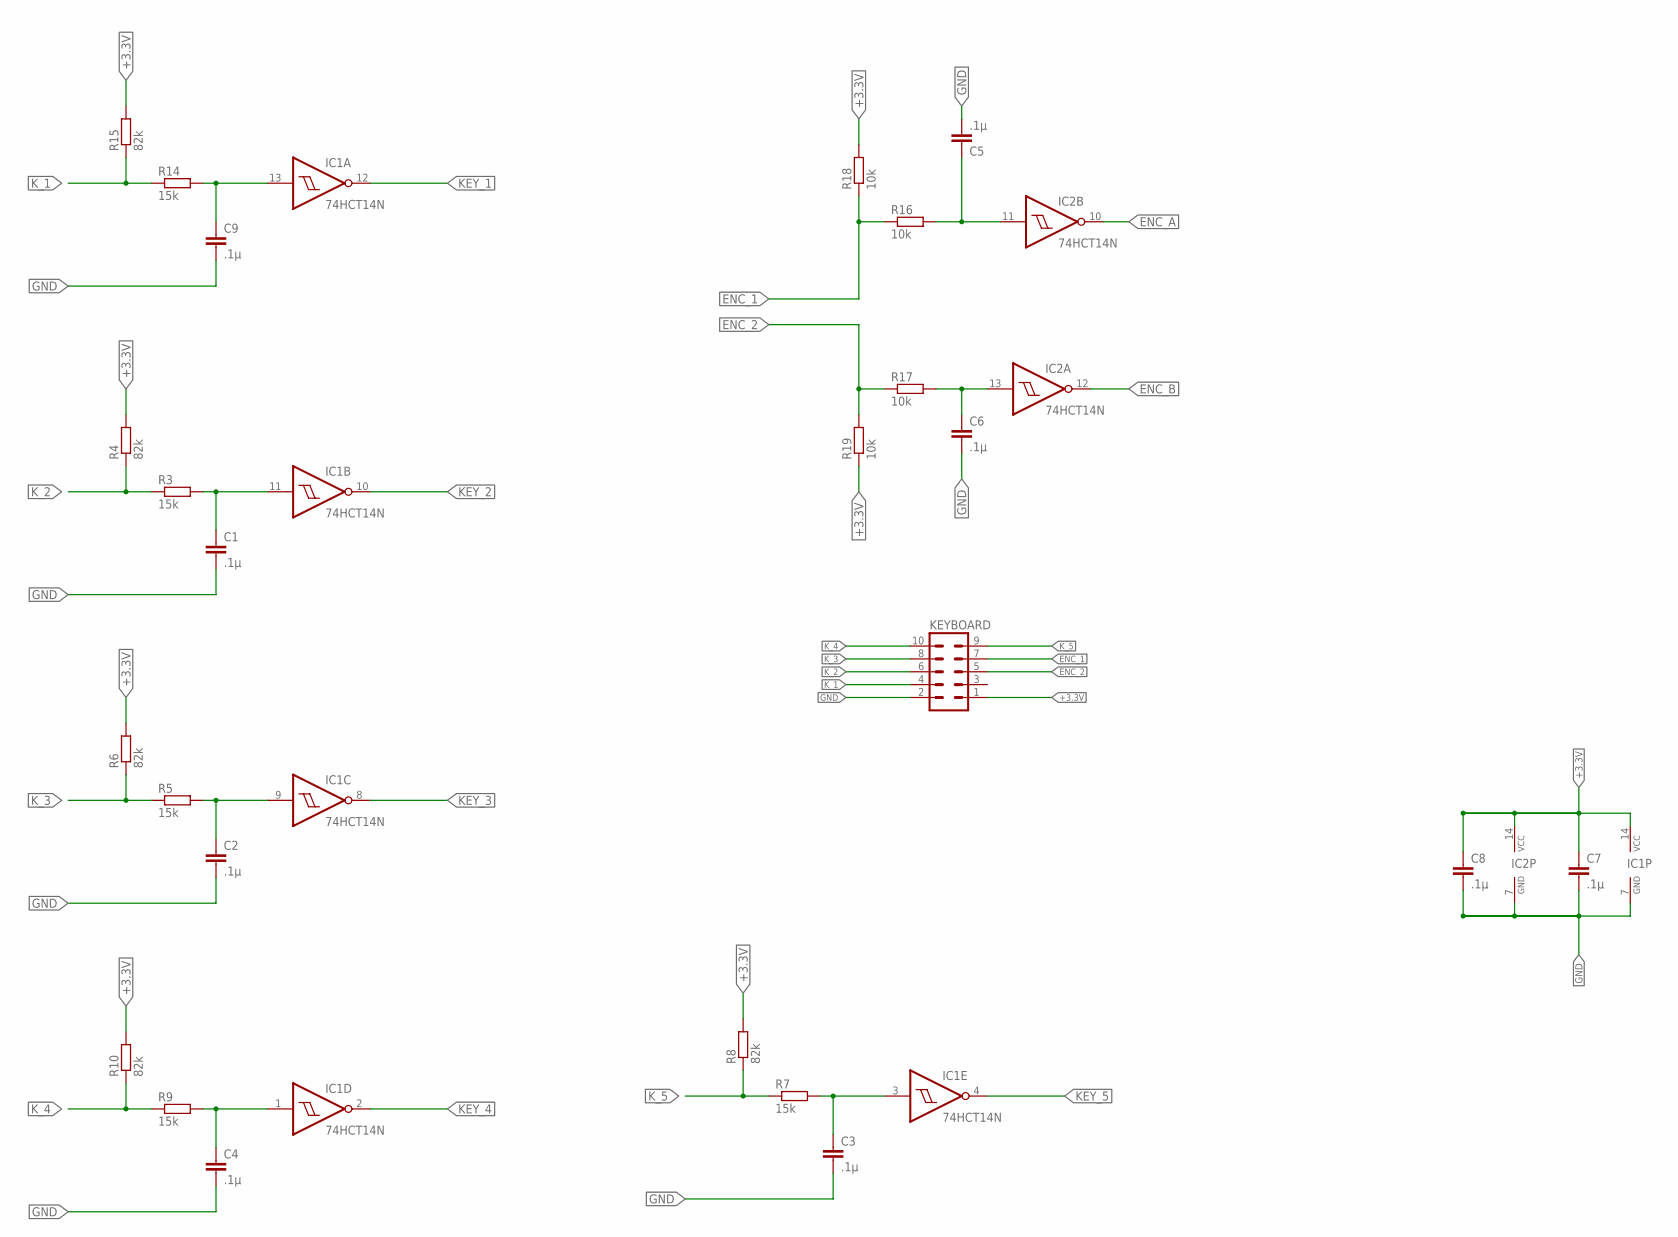
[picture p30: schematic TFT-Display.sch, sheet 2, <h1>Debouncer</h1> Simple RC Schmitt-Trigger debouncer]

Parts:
C1, C2, C3, C4, C5, C6, C7, C8, C9: .1µ; C025-024X044
IC1, IC2: 74HCT14N; DIL14
KEYBOARD: ML10L
R3, R5, R7, R9, R14: 15k; 0204/7
R4, R6, R8, R10, R15: 82k; 0204/7
R16, R17, R18, R19: 10k; 0204/7

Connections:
+3.3V: C7.1, C8.1, IC1.14 (VCC), IC2.14 (VCC), KEYBOARD.1, R4.2, R6.2, R8.2, R10.2, R15.2, R18.2, R19.1; also elsewhere on the board
ENC1: C5.1, IC2.11 (I), R16.2
ENC2: C6.1, IC2.13 (I), R17.2
ENC_1: KEYBOARD.7, R16.1, R18.1
ENC_2: KEYBOARD.5, R17.1, R19.2
ENC_A: IC2.10 (O); also elsewhere on the board
ENC_B: IC2.12 (O); also elsewhere on the board
GND: C1.2, C2.2, C3.2, C4.2, C5.2, C6.2, C7.2, C8.2, C9.2, IC1.7 (GND), IC2.7 (GND), KEYBOARD.2; also elsewhere on the board
K1: C9.1, IC1.13 (I), R14.2
K2: C1.1, IC1.11 (I), R3.2
K3: C2.1, IC1.9 (I), R5.2
K4: C3.1, IC1.3 (I), R7.2
K5: C4.1, IC1.1 (I), R9.2
KEY_1: IC1.12 (O); also elsewhere on the board
KEY_2: IC1.10 (O); also elsewhere on the board
KEY_3: IC1.8 (O); also elsewhere on the board
KEY_4: IC1.2 (O); also elsewhere on the board
KEY_5: IC1.4 (O); also elsewhere on the board
K_1: KEYBOARD.4, R14.1, R15.1
K_2: KEYBOARD.6, R3.1, R4.1
K_3: KEYBOARD.8, R5.1, R6.1
K_4: KEYBOARD.10, R9.1, R10.1
K_5: KEYBOARD.9, R7.1, R8.1

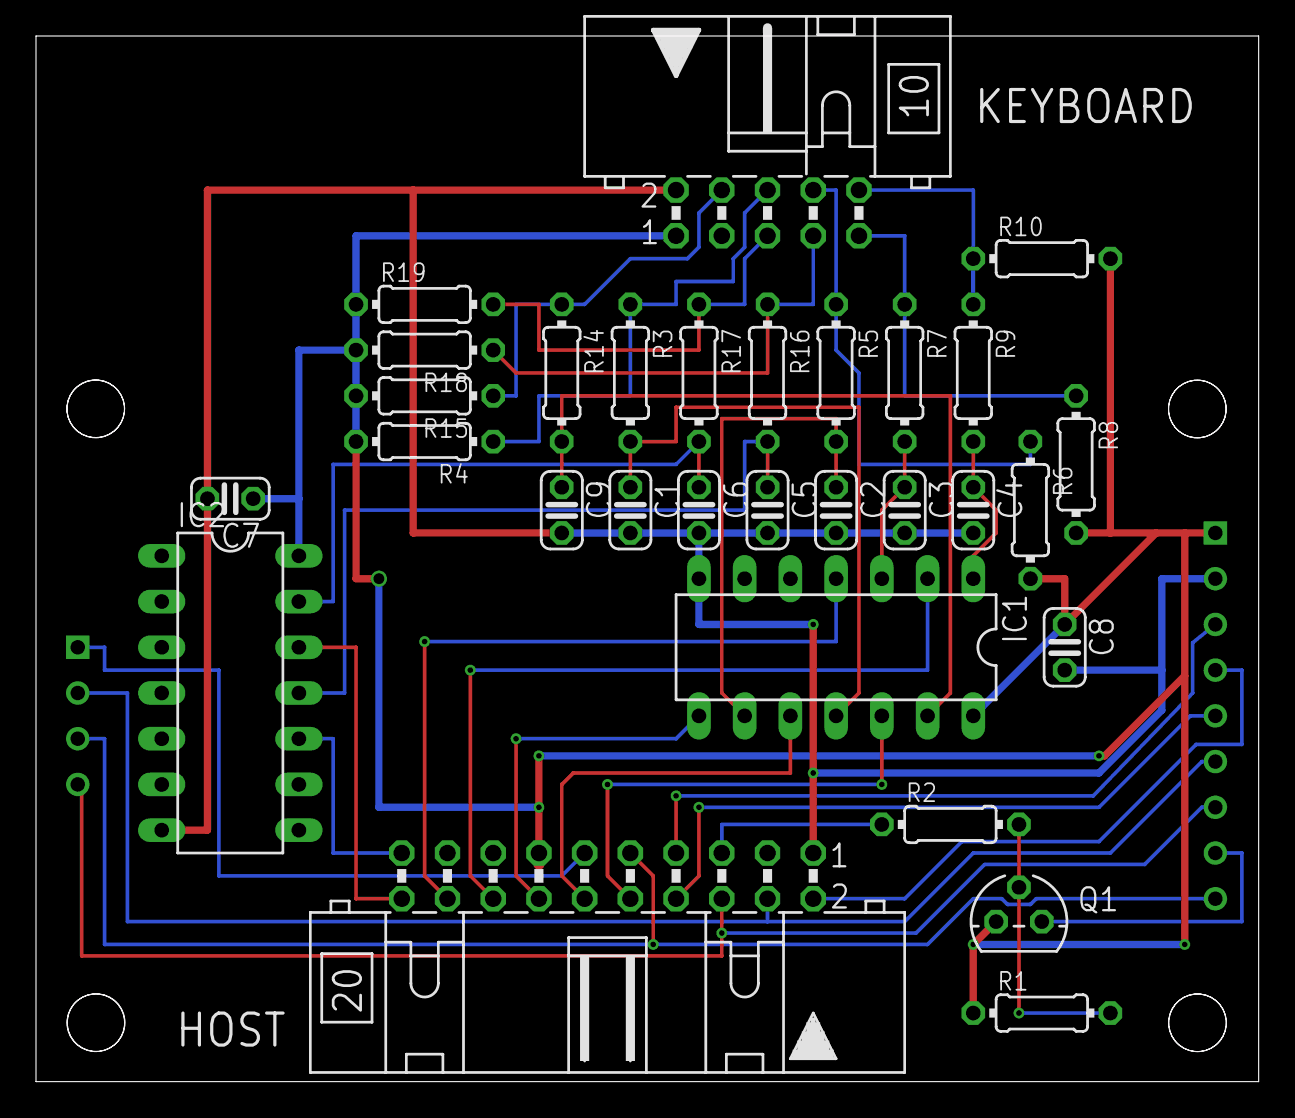
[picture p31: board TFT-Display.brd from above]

Board: 2 copper layers, 67.9 x 58.1 mm, 31 parts (1 on the bottom side), 33 nets.

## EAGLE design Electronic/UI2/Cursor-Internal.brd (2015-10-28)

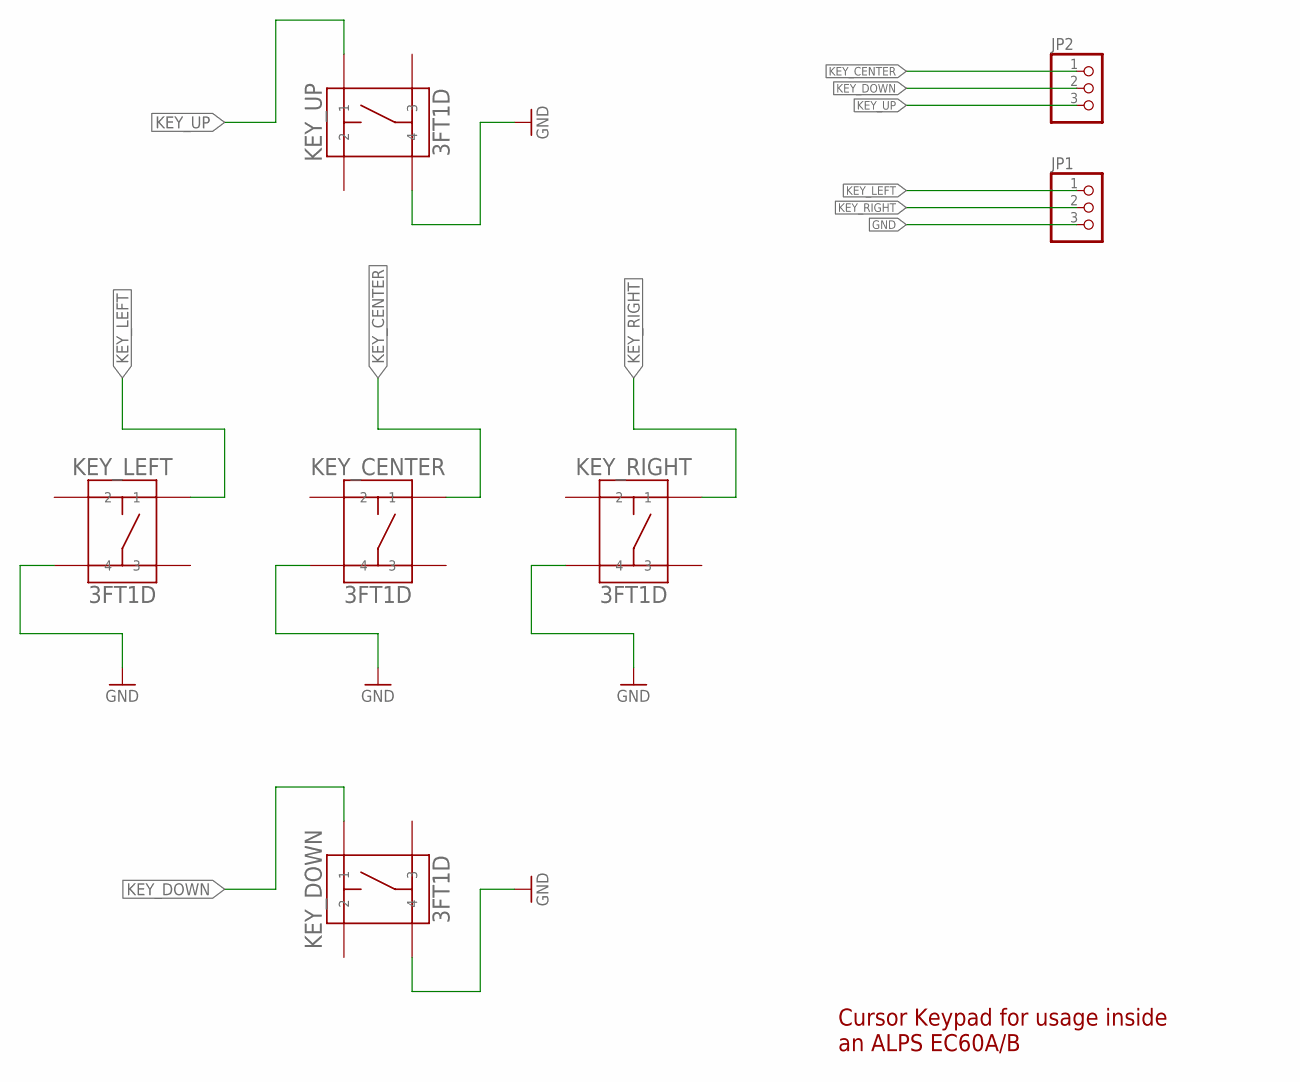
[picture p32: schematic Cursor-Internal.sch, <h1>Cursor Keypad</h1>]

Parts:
JP1, JP2: PINHD-1X3; 1X03
KEY_CENTER: 3FT1D; 3FT
KEY_DOWN: 3FT1D; 3FT
KEY_LEFT: 3FT1D; 3FT
KEY_RIGHT: 3FT1D; 3FT
KEY_UP: 3FT1D; 3FT

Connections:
GND: JP1.3, KEY_CENTER.P$4 (4), KEY_DOWN.P$4 (4), KEY_LEFT.P$4 (4), KEY_RIGHT.P$4 (4), KEY_UP.P$4 (4)
KEY_CENTER: JP2.1, KEY_CENTER.P$1 (1)
KEY_DOWN: JP2.2, KEY_DOWN.P$1 (1)
KEY_LEFT: JP1.1, KEY_LEFT.P$1 (1)
KEY_RIGHT: JP1.2, KEY_RIGHT.P$1 (1)
KEY_UP: JP2.3, KEY_UP.P$1 (1)

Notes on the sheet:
Cursor Keypad for usage inside an ALPS EC60A/B

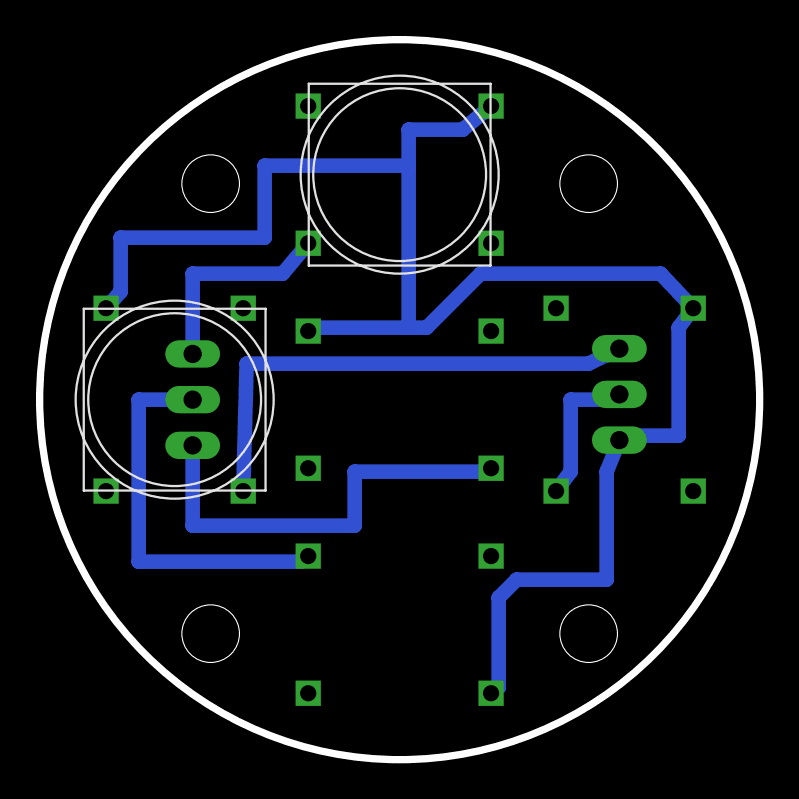
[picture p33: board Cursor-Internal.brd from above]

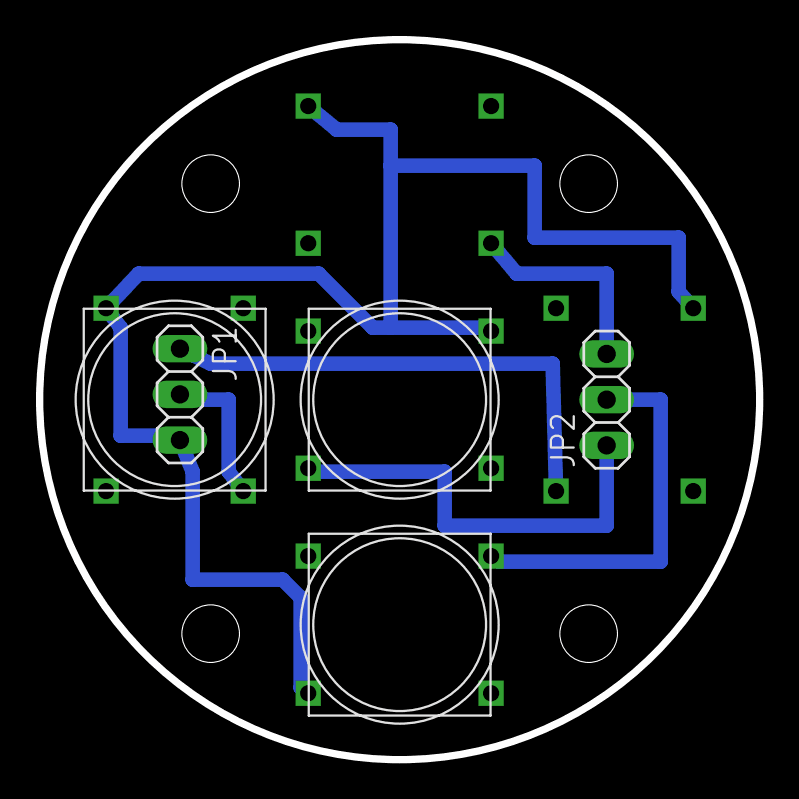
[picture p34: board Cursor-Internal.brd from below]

Board: 2 copper layers, 40.0 x 40.0 mm, 7 parts (5 on the bottom side), 6 nets.

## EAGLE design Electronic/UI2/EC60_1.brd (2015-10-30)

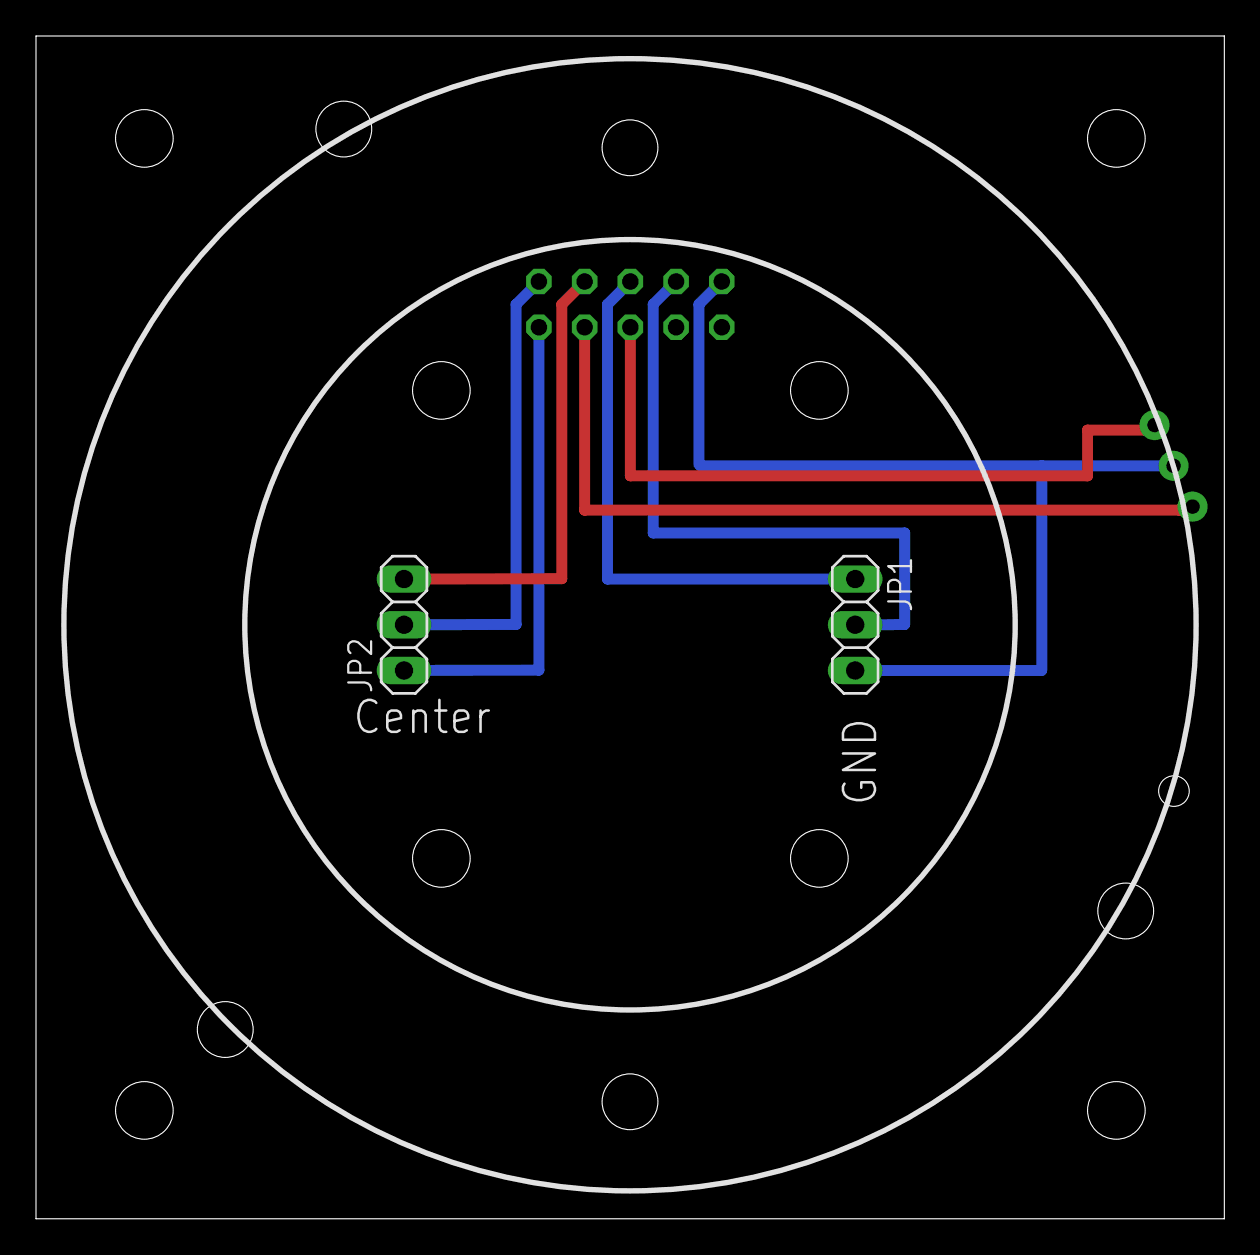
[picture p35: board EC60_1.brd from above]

Board: 2 copper layers, 66.0 x 65.7 mm, 4 parts (1 on the bottom side), 8 nets.

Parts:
JP1, JP2: 1X03
SV1: ML10L
U$1: EC60A

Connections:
ENC_1: SV1.5, U$1.A
ENC_2: SV1.7, U$1.B
GND: JP1.3, SV1.2, U$1.C
K_1: JP1.2, SV1.4
K_2: JP1.1, SV1.6
K_3: JP2.3, SV1.8
K_4: JP2.2, SV1.10
K_5: JP2.1, SV1.9

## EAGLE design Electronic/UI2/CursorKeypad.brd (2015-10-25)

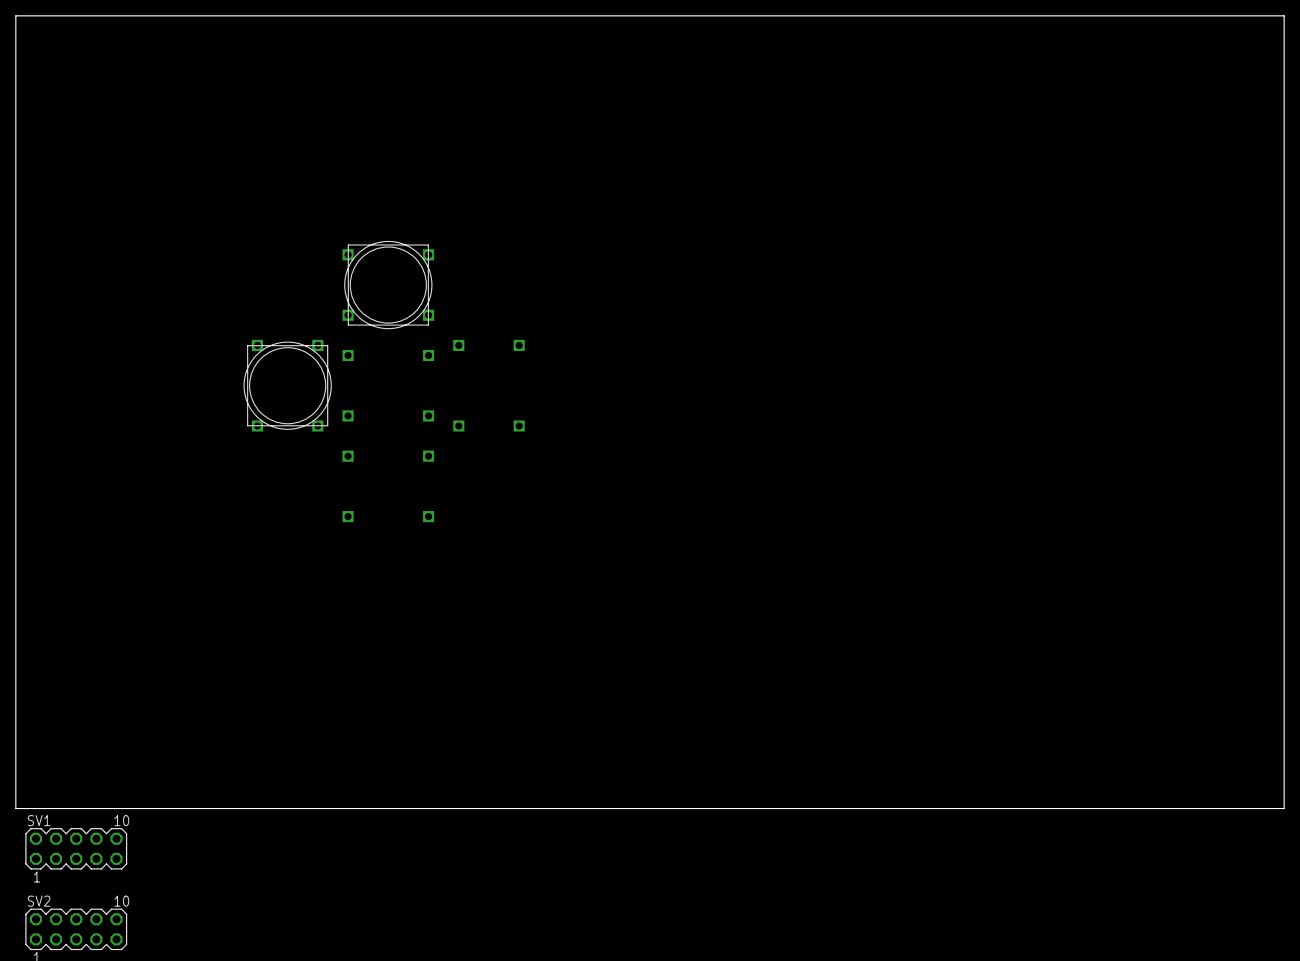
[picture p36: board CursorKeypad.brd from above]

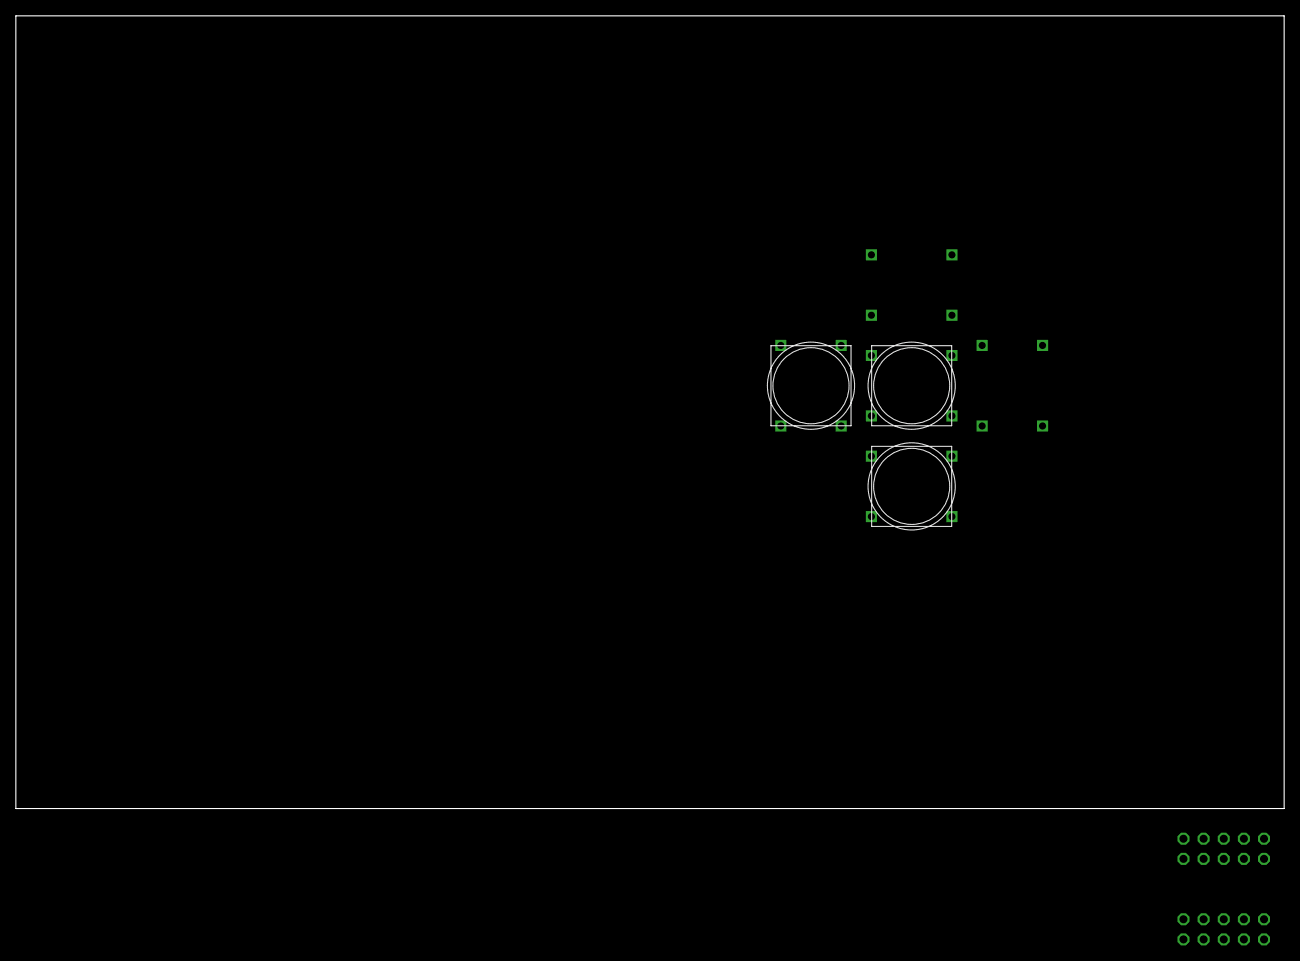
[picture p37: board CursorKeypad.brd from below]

Board: 2 copper layers, 160.0 x 100.0 mm, 7 parts (3 on the bottom side), 10 nets, no tracks yet.

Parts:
KEY_CENTER: 3FT1D; 3FT
KEY_DOWN: 3FT1D; 3FT
KEY_LEFT: 3FT1D; 3FT
KEY_RIGHT: 3FT1D; 3FT
KEY_UP: 3FT1D; 3FT
SV1: Debounce L; MA05-2
SV2: Debounce R; MA05-2

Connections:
GND: KEY_CENTER.P$3, KEY_CENTER.P$4, KEY_DOWN.P$3, KEY_DOWN.P$4, KEY_LEFT.P$3, KEY_LEFT.P$4, KEY_RIGHT.P$3, KEY_RIGHT.P$4, KEY_UP.P$3, KEY_UP.P$4, SV2.1, SV2.2
KEY_CENTER: KEY_CENTER.P$1, KEY_CENTER.P$2, SV1.9, SV1.10
KEY_DOWN: KEY_DOWN.P$1, KEY_DOWN.P$2, SV1.7, SV1.8
KEY_LEFT: KEY_LEFT.P$1, KEY_LEFT.P$2, SV1.3, SV1.4
KEY_RIGHT: KEY_RIGHT.P$1, KEY_RIGHT.P$2, SV1.1, SV1.2
KEY_UP: KEY_UP.P$1, KEY_UP.P$2, SV1.5, SV1.6
unnamed: SV2.9, SV2.10
unnamed: SV2.7, SV2.8
unnamed: SV2.5, SV2.6
unnamed: SV2.3, SV2.4

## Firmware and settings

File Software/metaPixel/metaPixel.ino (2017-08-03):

#define FASTLED_INTERNAL
//#define FASTLED_ALLOW_INTERRUPTS 1
/* #include <Audio.h>
#include <Wire.h>
#include <SPI.h>
#include <SD.h>*/

#include <Queue.h>
#include <FastLED.h>
#include <Streaming.h>
#include "VT100Stream.hpp"
#include <TeensyDmx.h>
#include <rdm.h>
#include <Arduino.h>

#include "metaPixel.h"
#include "Palettes.h"
#if USE_ILI9341_DISPLAY
#include "ILI9341_t3.h"
#endif

#define START_PROG 7

/**********************************************************
**
** Globals
**
**********************************************************/

CRGB  leds[NUM_LEDS];
#if USE_DOUBLE_BUFFER
CRGB  led_backbuffer[NUM_LEDS];
metaDisplay display= metaDisplay(leds,led_backbuffer,MODULES_WIDTH,MODULES_HEIGHT);
#else
metaDisplay display= metaDisplay(leds,NULL,MODULES_WIDTH,MODULES_HEIGHT);
#endif

/** DMX **/

#define DMX_REDE 30
struct RDMINIT rdmData {
	(char*)"TeensyDMX v0.1",
	(char*)"Teensyduino",
	1,  // Device ID
	(char*)"DMX Node",
	1,  // The DMX footprint
	0,  // The DMX startAddress - only used for RDM
	0,  // Additional commands length for RDM
	0   // Definition of additional commands
};
TeensyDmx DMX(Serial3, &rdmData, 30);

/** the global task queue */
Queue taskQueue;

#if USE_ILI9341_DISPLAY
ILI9341_t3 tft = ILI9341_t3(TFT_CS, TFT_DC,TFT_RST,TFT_MOSI,TFT_SCK,TFT_MISO);

tftSerial TFTSerial;
#endif



/**********************************************************
**
** Parameters
**
**********************************************************/

/** these are the parameters controlling global states */
AnimationValue Delay(10);												///< delay in ms between two calls to the Effect::frame method
AnimationValue EffectProgram(0);								///< index of the currently running effect program
AnimationValue Palette(0);											///< active palette
AnimationValue Brightness(BRIGHTNESS);					///< current brithness of the display
AnimationValue BlendParam(5);										///< detemines how fast the backbuffer is blended into the display buffer
AnimationValue MirrorParam(0);									///< current display mirror state
AnimationValue ResolutionParam(1);							///< current display resolution

/** these parameters are used by the Effects */
AnimationValue genericSpeed1(8);												///< generic parameter for Effects
AnimationValue genericSpeed2(1);												///< generic parameter for Effects
AnimationValue genericScale1(50);												///< generic parameter for Effects
AnimationValue genericScale2(50);												///< generic parameter for Effects
AnimationValue genericParam1(display.displayWidth());		///< generic parameter for Effects
AnimationValue genericParam2(display.displayWidth());		///< generic parameter for Effects
AnimationValue genericEffectMask1(HorizontalEffect | VerticalEffect | DiagonalEffect | CircleEffect);		///< generic parameter for Effects
AnimationValue genericEffectMask2(HorizontalEffect | VerticalEffect | DiagonalEffect | CircleEffect);		///< generic parameter for Effects
bool parameterHasChanged = false;

/**********************************************************
**
** Palettes
**
**********************************************************/

CRGBPalette16 colorPalettes[]={
	(CRGBPalette16)RainbowColors_p,
	(CRGBPalette16)CloudColors_p,
	(CRGBPalette16)OceanColors_p,
	(CRGBPalette16)ForestColors_p,
	(CRGBPalette16)PartyColors_p,
	(CRGBPalette16)RainbowStripeColors_p,
	(CRGBPalette16)LavaColors_p,
	(CRGBPalette16)HeatColors_p,
	(CRGBPalette16)arctic_gp,
	(CRGBPalette16)temperature_gp,
	(CRGBPalette16)colombia_gp,
	(CRGBPalette16)cequal_gp,
};
uint8_t numberOfPalettes = sizeof(colorPalettes)/sizeof(CRGBPalette16);

const char * SystemParameterName[]={
	"Program","Delay","Palette","Bright","Mirror","Fade","Res"
};
/** All of the accessible parameters */
Parameter16_t parameterArray[] = {
	// global scope parameters.
	// these parameters control  Program, framerate etc.
	/* 00 */ 	Parameter16_t('P',(int16_t)0,(int16_t)0,		&EffectProgram,String("Program")),
	/* 01 */	Parameter16_t('D',(int16_t)1,(int16_t)5000,	&Delay,String("Delay")),
	/* 02 */	Parameter16_t('C',(int16_t)0,(int16_t)0,		&Palette,String("Palette")),
	/* 03 */	Parameter16_t('B',(int16_t)0,(int16_t)255,	&Brightness,String("Brightness")),
	/* 04 */  Parameter16_t('Q',(int16_t)0,(int16_t)5,		&MirrorParam,String("Mirror")),
	/* 05 */	Parameter16_t('Z',(int16_t)1,(int16_t)14,		&BlendParam,String("Blend")),
	/* 06 */	Parameter16_t('A',(int16_t)0,(int16_t)1,		&ResolutionParam,String("Resolution")),

	// local parameters. These parameters have a different meening for each Effect program.
	/* 07 */	Parameter16_t('U',(int16_t)0,(int16_t)0,		&genericSpeed1,String()),
	/* 08 */  Parameter16_t('V',(int16_t)0,(int16_t)0,		&genericSpeed2,String()),
	/* 09 */	Parameter16_t('R',(int16_t)0,(int16_t)0,		&genericScale1,String()),
	/* 10 */	Parameter16_t('I',(int16_t)0,(int16_t)0,		&genericScale2,String()),
	/* 11 */	Parameter16_t('O',(int16_t)0,(int16_t)0,		&genericParam1,String()),
	/* 12 */ 	Parameter16_t('H',(int16_t)0,(int16_t)0,		&genericParam2,String()),
	/* 13 */	Parameter16_t('M',(int16_t)0,(int16_t)255,	&genericEffectMask1,String()),
	/* 14 */	Parameter16_t('N',(int16_t)0,(int16_t)255,	&genericEffectMask2,String()),
};


int16_t parameterArraySize = sizeof(parameterArray)/sizeof(Parameter16_t);

/**********************************************************
**
** Effects
**
**********************************************************/
EffectWhite 			whiteEffect 	= EffectWhite(&parameterArray[param_H],&parameterArray[param_R],&parameterArray[param_V]);
EffectFire  			fireEffect 		= EffectFire(&parameterArray[param_O],&parameterArray[param_H],&parameterArray[param_U]);
EffectNoise 			noiseEffect 	= EffectNoise(&parameterArray[param_R],&parameterArray[param_U],&parameterArray[param_V],&parameterArray[param_M]);
EffectPlasma 			plasmaEffect 	= EffectPlasma(&parameterArray[param_I],&parameterArray[param_U],&parameterArray[param_R],&parameterArray[param_V],&parameterArray[param_M]);
EffectColorBands 	colorBands 		= EffectColorBands(&parameterArray[param_R],&parameterArray[param_I],&parameterArray[param_U],&parameterArray[param_M]);
EffectLine 				lineEffect 		= EffectLine(&parameterArray[param_V]);
EffectWhitney 		whitneyEffect = EffectWhitney(&parameterArray[param_U],&parameterArray[param_R],&parameterArray[param_V]);
EffectWater 			waterEffect 	= EffectWater(&parameterArray[param_U],&parameterArray[param_O],&parameterArray[param_H],&parameterArray[param_V],&parameterArray[param_M]);

//EffectWhite dummy = EffectWhite();
//effectProgramN_t h = {dummy,1000,NULL};
effectProgramN_t effectProgramsN[] = {
	{&whiteEffect,100,NULL},
	{&noiseEffect,150,NULL}, //"*rU6C8!R20 80 60"
	{&plasmaEffect,150,"D150B160Z8U12V2I6R10M15"},
	{&colorBands,150,"I800R2U30Z6"},
	{&lineEffect,65,"v5z2"},
	{&fireEffect,60,"O70H150U70D60Z12000"},
	{&whitneyEffect,67,NULL},
	{&waterEffect,40,NULL},
};
uint8_t newMaxPrograms = sizeof(effectProgramsN) / sizeof(effectProgramN_t);

/// Predefined effect macros
const char* macroStrings[] = {
/* 0 Startup 		*/	"q0A0#1#8A1#9",
/* 1 Noise D.		*/	"p1&0R15U3V3M1D80C8Z3&20c0&20@u3,8,30@z5,12,30@r15,20,30@v6,1,15%vm5&20v253@u8,5,30@z12,3,30@r20,35,30%z&15m1c8&30",
/* 2 Plasma  		*/	"p2&60",
/* 3 Color B 		*/	"p3&60",
/* 4 Lines   		*/	"p4&60",
/* 5 Fire    		*/	"p5&10@O70,8,30@U70,10,30%O&10@o8,77,30h160@u10,70,10%O&15@o77,65,20@u10,66,10%Oh150",
/* 6 Whitney 1 	*/	"p6&0C0Z1U180R400V1&5 @r400,120,30@z1,5,60%r@r120,30,50%r@z5,10,61%z&34#7",
/* 7 Whitney 2 	*/	"q5c0@r400,120,30%r@r120,30,30@z1,13,60%zq4c5&90c0&30",
/* 8 Water			*/	"p7&0c8U15O35H0v80M0z14&1@o35,460,30@z14,8,60%zc2m2v120o800&20z10v120o322m0u18&60",
/* 9 Endless		*/ 	"q0#1#2#3#4#5#8#6#8q5#1#5#4#8#9",
};
int16_t maxMacroStrings = sizeof(macroStrings)/sizeof(const char*);
const char* macroNames[]={
	"Default",
	"Noise Demo",
	"Plasma Demo",
	"Colorbands Demo",
	"Lines Demo",
	"Fire Demo",
	"Whitney Demo1",
	"Whitney Demo2",
	"Water Demo",
	"Endless Demo"
};
/**********************************************************
**
** DEBUG & Helpers
**
**********************************************************/
#if USE_ILI9341_DISPLAY
int16_t TFT_LogoEnd = 0;

void drawLogo()
{
	tft.setTextSize(5);
	tft.setCursor(25,15);
	tft.setTextColor(ILI9341_GREEN);
	tft<<"metaPixel";
	tft.drawFastHLine(tft.getCursorX(),tft.getCursorY()+10,tft.width(),ILI9341_GREEN);
	tft.setTextColor(ILI9341_YELLOW);
	tft.setTextSize(2);
	tft<<endl;
	TFT_LogoEnd =0; //tft.cursor_y;
}

void initializeTFT()
{
	tft.begin();

	tft.setRotation(3);
	tft.fillScreen(ILI9341_BLACK);
	tft.setTextWrap(true);
	analogWrite(TFT_LED,100);
	drawLogo();
}

bool runningTFT;
unsigned long testText() {

	runningTFT = true;
  tft.fillScreen(ILI9341_BLACK);
  unsigned long start = micros();
  tft.setCursor(0, 0);
  tft.setTextColor(ILI9341_WHITE);  tft.setTextSize(1);
  tft.println("Hello World!");
  tft.setTextColor(ILI9341_YELLOW); tft.setTextSize(2);
  tft.println(1234.56);
  tft.setTextColor(ILI9341_RED);    tft.setTextSize(3);
  tft.println(0xDEADBEEF, HEX);
  tft.println();
  tft.setTextColor(ILI9341_GREEN);
  tft.setTextSize(5);
  tft.println("Groop");
  tft.setTextSize(2);
  tft.println("I implore thee,");
  tft.setTextSize(1);
  tft.println("my foonting turlingdromes.");
  tft.println("And hooptiously drangle me");
  tft.println("with crinkly bindlewurdles,");
  tft.println("Or I will rend thee");
  tft.println("in the gobberwarts");
  tft.println("with my blurglecruncheon,");
  tft.println("see if I don't!");
	runningTFT = false;
  return micros() - start;
}

void dumpTFTParameters()
{

	tft.setTextWrap(false);
	//uint16_t line = 1;
	uint16_t column = 0;
	uint16_t t = EffectProgram.currentValue()%(newMaxPrograms);
	Effect *effect = effectProgramsN[t].program;
	//	tft.fillRect(0,TFT_LogoEnd,tft.width(),tft.height()-TFT_LogoEnd,ILI9341_BLACK);
	tft.setCursor(0,TFT_LogoEnd);
	tft.setTextSize(2);
	tft.setTextColor(ILI9341_YELLOW);
	tft.fillRect(0,tft.getCursorY(),tft.width(),2*7,ILI9341_BLACK); tft<<"Effect: "<<effect->getName()<<endl;tft.setCursor(tft.getCursorX(),tft.getCursorY()+3);
	tft.fillRect(0,tft.getCursorY(),tft.width(),2*7,ILI9341_BLACK);tft<<"Parameter:"<<endl;tft.setCursor(tft.getCursorX(),tft.getCursorY()+4);
	size_t params = effect->numberOfParameters();
	tft.fillRect(0,tft.getCursorY(),tft.width(),2*7,ILI9341_BLACK);
	for(size_t i=0;i<params;i++){
		tft << effect->parameterNameAt(i);
		column +=TFT_NAME_CELL_LENGTH*6*tft.getTextSize();
		tft.setCursor(column,tft.getCursorY());
		tft << effect->parameterAt(i)->value->currentValue();
		column +=6*5*tft.getTextSize();
		tft.setCursor(column,tft.getCursorY());
		if(column > (tft.width()-40)){
			tft<<endl;tft.setCursor(tft.getCursorX(),tft.getCursorY()+4);
			tft.fillRect(0,tft.getCursorY(),tft.width(),2*7,ILI9341_BLACK);
			column = 0;
			tft.setCursor(column,tft.getCursorY());
		}
	}
	if(column!=0){
		tft<<endl;tft.setCursor(0,tft.getCursorY()+6);
	}else{
		tft.setCursor(0,tft.getCursorY()+6);
	}
	column=0;
	tft.fillRect(0,tft.getCursorY(),tft.width(),2*7,ILI9341_BLACK);
	for(int i=0;i<7;i++){
		tft<< SystemParameterName[i];
		column +=TFT_NAME_CELL_LENGTH*6*tft.getTextSize();
		tft.setCursor(column,tft.getCursorY());
		tft<< parameterArray[i].value->currentValue();
		column +=6*5*tft.getTextSize();
		tft.setCursor(column,tft.getCursorY());
		if(column>(tft.width()-40)){
			tft<<endl;tft.setCursor(tft.getCursorX(),tft.getCursorY()+4);
			tft.fillRect(0,tft.getCursorY(),tft.width(),2*7,ILI9341_BLACK);
			column = 0;
			tft.setCursor(column,tft.getCursorY());		}
	}

}
#endif
void dumpParameters()
{
	#if USE_ILI9341_DISPLAY
	dumpTFTParameters();
	#endif
	uint8_t line = 1;
	uint8_t column = 1;
	uint16_t t = EffectProgram.currentValue()%(newMaxPrograms);
	Effect *effect = effectProgramsN[t].program;
	Serial << ScreenPos(line++,column)<<clearLineRight<<effect<<endl;
	Serial << ScreenPos(line++,column)<<clearLineRight<<"Parameter:";
	line = 3;
	Serial<<ScreenPos(line,1)<<clearLineRight;
	size_t params = effect->numberOfParameters();
	for(size_t i=0;i<params;i++){
		Serial << ScreenPos(line,column)<<effect->parameterNameAt(i);
		column +=NAME_CELL_LENGTH;
		Serial << ScreenPos(line,column)<<*effect->parameterAt(i);
		column +=PARAMETER_CELL_LENGTH;
		if(column > LINE_LENGTH){
			line ++;
			column = 1;
			Serial << ScreenPos(line,column)<<clearLineRight;
		}
	}
	//effect->printParameter(Serial);
	line = 6;
	column =1;
	for(int i=0;i<7;i++){
		Serial << ScreenPos(line,column)<<SystemParameterName[i];
		column +=NAME_CELL_LENGTH;
		Serial <<ScreenPos(line,column)<<parameterArray[i]<<endl;
		column +=PARAMETER_CELL_LENGTH;
		if(column>LINE_LENGTH){
			line ++;
			column = 1;
			Serial<<ScreenPos(line,column)<<clearLineRight;
		}
	}

	// collect parameter String
	// String paramString = String(" ");
	// for(size_t i=0;i<6;i++){
	// 	String * k = parameterArray[i].getCommandString();
	// 	paramString += (*k);
	// }
	// for(size_t i=0;i<params;i++){
	// 	String *k = (effect->parameterAt(i))->getCommandString();
	// 	paramString +=(*k);
	// }
	// Serial <<ScreenPos(line++,0)<<clearLineRight<<paramString;
	line ++;
	Serial <<ScreenPos(++line,1)<<clearLineRight<<">";
}


/**********************************************************
**
** Arduino
**
**********************************************************/

elapsedMillis commandQueueTimer = 0;
void setup()
{
	random16_add_entropy( random());
	/** Setup TFT **/
	#if USE_ILI9341_DISPLAY
	initializeTFT();
	#endif

	FastLED.addLeds<CHIPSET, LED_PIN, COLOR_ORDER>(leds, NUM_LEDS).setCorrection(COLOR_CORRECTION);
	FastLED.clear(true);
	FastLED.setBrightness( BRIGHTNESS );
	FastLED.show();
	Serial.begin(115200);
	delay(100);

	#if USE_ILI9341_DISPLAY
	TFTSerial <<"Startup"<<endl;
	#endif
	// tweak global parameter max for Programs and pallettes
	parameterArray[0].maxValue = newMaxPrograms-1;
	parameterArray[2].maxValue = numberOfPalettes-1;

	/** Setup DMX **/
	DMX.setMode(TeensyDmx::Mode::DMX_IN);

	#if USE_ILI9341_DISPLAY
	TFTSerial << "Init Parameters"<<endl;
	#endif
	//	tft<<"Init Parameters"<<endl;

	/** initialize Effects **/
	EffectProgram.initTo(START_PROG);
	int16_t cP = EffectProgram.currentValue();
	Delay.initTo(effectProgramsN[cP].delay);
	Brightness.initTo(BRIGHTNESS);
	Palette.initTo(0);

	/** initialize Queued Task */
	#if USE_ILI9341_DISPLAY
	TFTSerial << "Starting Tasks"<<endl;
	#endif


	/** Double buffering **/
	#if USE_DOUBLE_BUFFER
	taskQueue.scheduleFunction(backbufferBlender,NULL,"BBB ",0,20);
	#endif

	/** Debug blinker (legacy) **/
	#if DEBUG_BLINK
	taskQueue.scheduleFunction(blinker,NULL,"BLNK",1000,1000);
	#endif

	/** Effect scheduler **/
	#if USE_EFFECT_SCEDULER
	taskQueue.scheduleFunction(effectRunner,NULL,"EFFC",0,Delay.currentValue());
	#endif


	/** Command line interface **/
	#if USE_ILI9341_DISPLAY
	TFTSerial << "Init Commandline Interface"<<endl;
	#endif
	#if USE_SERIAL_COMMANDS
	taskQueue.scheduleFunction(serialReader,NULL,"SERI",100,100);
	#endif
	#if USE_STARTUP_MACRO
	commandProcessor(macroStrings[0]);
	#endif
	randomSeed(millis());
	#if USE_ILI9341_DISPLAY
	TFTSerial<<"metaPixel initialized"<<endl;
	TFTSerial<<"Parameters: "<<parameterArraySize<<endl;
	TFTSerial<<"Programms: "<<newMaxPrograms<<endl;
	TFTSerial <<"Current Tasks:"<<taskQueue._itemsInQueue<<endl<<endl;
	delay(3000);
	tft.fillRect(0,TFT_LogoEnd,tft.width(),tft.height()-TFT_LogoEnd,ILI9341_BLACK);
	#endif
}

void loop()
{

	//
	// switch program Slot 0
	//
	if(EffectProgram.hasChanged()){
		int16_t nextP = EffectProgram.nextValue();
		#if DEBUG_LOOP
		int16_t currentP = EffectProgram.currentValue();
		Serial <<"CP: "<< currentP<<" NP:"<<nextP<<" ";
		#endif
		Delay = effectProgramsN[nextP].delay;
		EffectProgram.syncValue();
		#if 0 && DEBUG_LOOP
		Serial << " PQueue" << taskQueue._itemsInQueue<<endl;
		#endif
		parameterHasChanged = true;
	}

	//
	// switch delay (Slot 1)
	//
	if(Delay.hasChanged()){
		#if DEBUG_LOOP
		Serial<<"Delay from:"<<Delay.currentValue()<<" To:"<<Delay.nextValue()<<" ";
		#endif
		#if USE_EFFECT_SCEDULER
		taskQueue.scheduleChangeFunction("EFFC",Delay.nextValue(),Delay.nextValue());
		#endif
		Delay.syncValue();
		#if 0 & DEBUG_LOOP
		Serial << "DQueue" << taskQueue._itemsInQueue<<endl;
		#endif
		parameterHasChanged = true;
	}
	//
	// switch palette Slot(2)
	//
	if(Palette.hasChanged()){
		parameterHasChanged = true;
		Palette.syncValue();
		#if DEBUG_LOOP
		Serial << "Palette changed to "<<Palette.currentValue()<<endl;
		#endif
	}

	//
	// switch brightness Slot(3)
	//
	if(Brightness.hasChanged()){
		#if DEBUG_LOOP
		Serial <<"B:"<<Brightness.currentValue()<<endl;
		#endif
		FastLED.setBrightness(Brightness.nextValue());
		Brightness.syncValue();
		parameterHasChanged=true;
	}

	//
	// switch mirror mode Slot(4)
	//
	if(MirrorParam.hasChanged()){
		MirrorParam.syncValue();
		display.setMirrorMode((displayMirror)MirrorParam.currentValue());
		parameterHasChanged=true;
	}
	//
	// switch BlendParam
	//
	if(BlendParam.hasChanged()){
		BlendParam.syncValue();
		parameterHasChanged = true;
	}

	//
	// switch resolution
	//
	if(ResolutionParam.hasChanged()){
		ResolutionParam.syncValue();
		display.setResolution((ResolutionParam.currentValue()==0)?lowRes:highRes);
		parameterHasChanged=true;
	}

	/** check all remaining parameters */
	{
		bool t = false;
		for(int i=param_StartEffect;i<parameterArraySize-1;++i){
			t = t || parameterArray[i].value->syncValue();
		}
		if(t || parameterHasChanged){
			dumpParameters();
			parameterHasChanged = false;
			t= false;
		}
	}
	/** run all sequence tasks */
	taskQueue.Run(millis());

	commandQueue.processQueue();
	/** Create output on command processing **/
	if(commandQueueTimer>1000){
		if(commandQueue.waiting){
			Serial << ScreenPos(12,1)<<clearLineRight<<commandQueue<<endl;
		}
		Serial << clearLineRight;
		Serial << clearDown;
		commandQueueTimer = 0;
		//		dumpTFTParameters();
	}
	#if DEBUG_LOOP
	{
		static int p = 0;
		Serial <<ScreenPos(32,0)<<clearLineRight<<ScreenPos(22,p++)<< " . ";
		p= p%30;
	}
	#endif
	delay(2);
}

/**********************************************************
**
** backbuffer
**
**********************************************************/
int backbufferBlender(unsigned long now, void* userdata)
{
	#if USE_ILI9341_DISPLAY
	if(runningTFT)
		return 0;
	#endif

	uint8_t frac = (BlendParam.currentValue()*600)/Delay.currentValue();
	static uint8_t lastFrac =0;
	if(frac != lastFrac){
		//		Serial << "frac"<<frac<<endl;
		lastFrac = frac;
	}

	#if DEBUG_EFFECTS
	Serial <<".";
	#endif
	// if(frac < 4){
	// 	#if DEBUG_EFFECTS
	// 	Serial << "Frac cliped to 4, was "<<frac<<endl;
	// 	#endif
	// 	frac = 4;
	// }
	for(uint16_t i=0;i<NUM_LEDS;i++){
		leds[i]=nblend(leds[i],led_backbuffer[i],frac);
	}
	if( millis() < 5000 ) {
		FastLED.setBrightness( scale8( Brightness.currentValue(), (millis() * 256) / 5000));
	} else {
		FastLED.setBrightness(Brightness.currentValue());
	}
	FastLED.show();
	return 0;
}

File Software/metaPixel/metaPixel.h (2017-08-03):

/**
@file: metaPixel.h
@description: MasterHeaderfile containing all global definitions
*/
#ifndef __METAPIXEL_H__
#define __METAPIXEL_H__
#define FASTLED_INTERNAL

/** Feature Switsches **/
#define USE_EFFECT_SCEDULER 1
#define USE_SERIAL_COMMANDS 1
#define USE_DOUBLE_BUFFER 	1
#define USE_ILI9341_DISPLAY 0
#define USE_STARTUP_MACRO 	1


/*#include <Audio.h>
#include <Wire.h>
#include <SPI.h>
#include <SD.h>*/
#include <Queue.h>
#include <FastLED.h>
#include <Streaming.h>
#include "VT100Stream.hpp"
#include <TeensyDmx.h>
//#include <AudioStream.h>
#include <rdm.h>
#if USE_ILI9341_DISPLAY
#include "ILI9341_t3.h"
#endif

//#include "SPI.h"

/** display configuration **/
#define MODULES_WIDTH   5												// number of modules in X
#define MODULES_HEIGHT  4											  // number of modules in Y
#define MODULE_WIDTH    4												// width of module in pixels
#define MODULE_HEIGHT   5												// height of modules in pixels
#define DISPLAY_WIDTH   (MODULES_WIDTH * MODULE_WIDTH)
#define DISPLAY_HEIGHT  (MODULES_HEIGHT * MODULE_HEIGHT)

#if USE_ILI9341_DISPLAY
/** TFT Configuration **/
#define TFT_RST   2
#define TFT_DC    9
#define TFT_CS    10
#define TFT_MISO  12
#define TFT_MOSI  11
#define TFT_SCK   13
#define TFT_LED   6
#endif

/** Local Libraries **/
#include "Types.h"

#include "metaModule.hpp"
#include "metaDisplay.hpp"

#define NUM_LEDS (DISPLAY_WIDTH * DISPLAY_HEIGHT)
#include "Commands.hpp"
#include "Effect.hpp"
#include "Parameter.hpp"
#include "EffectWhite.hpp"
#include "EffectFire.hpp"
#include "EffectNoise.hpp"
#include "EffectPlasma.hpp"
#include "EffectColorBands.hpp"
#include "EffectLine.hpp"
#include "EffectWhitney.hpp"
#include "EffectWater.hpp"


/** Configuration  & global defaults**/
#define COLOR_ORDER       GRB
#define CHIPSET           WS2812
#define COLOR_CORRECTION  0xffeeff
#define BRIGHTNESS        160


#define DMXBase	          17
#define DMXSpan           7

#define LED_PIN           4

/** Audio configuration **/
#define AUDIO_INPUT AUDIO_INPUT_MIC

/** DEBUG CONFIGURATION **/
#define DEBUG (1)
#define DEBUG_BLINK   (0 & DEBUG & !USE_TEENSY_AUDIO_LAYOUT)
#define DEBUG_EFFECTS (0 & DEBUG)
#define DEBUG_ENCODER (0 & DEBUG)
#define DEBUG_MENU    (0 & DEBUG)
#define DEBUG_PARSER	(0 & DEBUG)
#define DEBUG_SERIAL  (0 & DEBUG)
#define DEBUG_COMMAND (0 & DEBUG)
#define DEBUG_LOOP		(0 & DEBUG)
#define DEBUG_EFFECT_SCEDULER (1 & DEBUG)

/** settings serial masks **/
#define NAME_CELL_LENGTH      10
#define TFT_NAME_CELL_LENGTH   8
#define PARAMETER_CELL_LENGTH 20
#define LINE_LENGTH           75
/** exporting globals **/
extern CRGB leds[];               ///< primary framebuffer
#if USE_DOUBLE_BUFFER
extern CRGB  led_backbuffer[];    ///< backbuffer
#endif
class metaDisplay;
extern metaDisplay display;          ///< global display class

extern TeensyDmx DMX;             ///< DMX Interface
extern Queue taskQueue;           ///< task queue scheduler
extern CRGBPalette16 colorPalettes[];
/** global effects parameter **/

extern AnimationValue EffectProgram;     ///< current running effect program
extern AnimationValue Delay;             ///< frame delay for the running effect
extern AnimationValue Palette;           ///< actual used palette
extern AnimationValue Brightness;        ///< global brightness of the display
extern AnimationValue BlendParam;        ///< factor for double buffer blending
extern AnimationValue MirrorParam;       ///< global display mirror mode

/** effect specific parameter **/
extern AnimationValue genericSpeed1;       ///< generic global parameter
extern AnimationValue genericSpeed2;       ///< generic global parameter
extern AnimationValue genericScale1;       ///< generic global parameter
extern AnimationValue genericScale2;       ///< generic global Parameter

extern AnimationValue genericParam1;       ///< generic global parameter
extern AnimationValue genericParam2;       ///< generic globa Parameter

extern AnimationValue genericEffectMask1;     ///< generic global mask parameter
extern AnimationValue genericEffectMask2;     ///< generic global Mask 2

extern effectProgramN_t effectProgramsN[];
extern uint8_t newMaxPrograms;

extern Parameter16_t parameterArray[];
extern int16_t parameterArraySize;

extern void dumpParameters();
extern CommandQueue commandQueue;

extern bool parameterHasChanged;

extern const char* macroStrings[];
extern int16_t maxMacroStrings;
extern const char* macroNames[];

typedef enum{param_P,param_D,param_C,param_B,param_Q, param_Z,param_A,param_U,param_V,param_R,param_I,param_O,param_H,param_M,param_N,param_StartEffect=param_U } paramID;


#if USE_ILI9341_DISPLAY
extern ILI9341_t3 tft;

class tftSerial : public Print
{
public:
	tftSerial(){};
	size_t write(uint8_t c){
		Serial.write(c);
		#if USE_ILI9341_DISPLAY
			tft.write(c);
		#endif
		return 1;
	}
};
extern tftSerial TFTSerial;
#endif
#endif

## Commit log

2015-08-07 initial commit
    of all the stuff done till now
    [Box-BL.stl, Box-BR.stl, Box-MC.stl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]
2015-08-10 Sharing parameters between noise and plasma
    [Plasma2.ino, metaPixel.ino]
2015-08-11 main controller board layout with DMX client only
    [MetaPixel3-Full.brd, MetaPixel3-Full.sch, metaPixel.brd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]
2015-08-14 Next generation
    [metaPixel-Audio.sch]
2015-08-17 procrastinating - minor changes to the Audio version -
    [metaPixel-Audio.sch]
2015-08-18 new effect/parameter structure up and running
    All effects use the new parameter and effect structure
    Menu and Encoder UI disabled
    Teensy Audio shield compatibility
2015-08-19 further reworking of old structures
    [metaPixel.h, metaPixel.ino]
2015-08-20 Audio switchable
2015-08-22 fixed parameter animation for target<current
    [EffectFire.cpp]
2015-08-24 Removing a couple of eagle files
2015-08-29 fixing parser problem
    adding shaped mirror mode
    [metaPixel.h, metaPixel.ino]
2015-09-01 command rework
    removed all command parser
    added parameter names to effects
    added more beautiful VT100 output
    [metaPixel.h, metaPixel.ino]
2015-10-14 WaitForAnimation
    - removing dependency to TeensyAudio
2015-10-17 added Documentation for the 2.2" ledsee tat display
    [282838p.obj]
2015-10-18 Stuff
    resolution switch for display
    renaming of globals
    output of parameter settings adapts automatically to new parameters
    [metaPixel-Audio.sch]
2015-10-20 Added an ILI9341 Display
    [metaPixel-Audio.brd, metaPixel-Audio.sch]
2015-10-20 removing Audio Configuration
    moving SPI to default for ILI
    removing legacy stuff.
    moving to current ILI lib
    [metaPixel3V2.brd, metaPixel3V2.sch]
2015-10-21 fixing include stuff
    [metaPixel3V2.brd, metaPixel3V2.sch]
2015-10-22 Planing a new UI Board
    [CursorKeypad.brd, CursorKeypad.sch]
2015-10-22 new UI
    [CursorKeypad.brd, CursorKeypad.sch]
2015-10-23 planing a new UI concept
    [DebounceEncoder.sch]
2015-10-25 Updated connectors
    and more work on the UI Boards
    [CursorKeypad.brd, CursorKeypad.sch, DebounceEncoder.sch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]
2015-10-28 adding a new CursorCross for EC60A/B usage
    [Cursor-Internal.brd, Cursor-Internal.sch]
2015-10-29 new Keycross and EC60A board
    [Cursor-EC60.brd, Cursor-EC60.sch, DebounceEncoder.sch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]
2015-10-29 Removing the obsolete test code
    which was provided by the Chinese source
    [282838p.obj]
2015-10-29 board positions
    [EC60_1.brd, EC60_1.sch]
2015-10-30 removing a couple of unused libs
2015-10-30 Building the UI-Board
    [Cursor-EC60.brd, Cursor-EC60.sch, CursorKeypad.brd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]
2015-10-30 Display board layout
    [Cursor-EC60.brd, DebounceEncoder.sch, TFT-Display.brd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]
2015-11-03 The first 3 Boards are ready
    [Cursor-EC60.brd, Cursor-EC60.sch, EC60_1.brd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]
2015-11-04 the mainboard
    [metaPixel-Controller.brd, metaPixel-Controller.sch]
2015-11-04 Layout 1
    [metaPixel-Controller.brd, metaPixel-Controller.sch]
2015-11-10 minor changes
    [EC60_1.brd, EC60_1.sch, TFT-Display.brd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]
2015-11-19 adding a couple of data sheets
    [TFT-Display.brd]
2015-11-22 Reworking the Controller
    [TFT-Display.brd, TFT-Display.sch]
2015-11-29 Fixing analog backlightproblem
    creating a couple of view helper classes.
    adding Display brightens control.
2015-12-03 switching LED pin
2015-12-09 switching views and actions
2015-12-10 encoder acceleration
2016-01-27 Double LED ring
2016-01-27 Removing the TFT from the Debouncer
    [DebounceEncoder.sch, Debouncer.brd, Debouncer.sch]
2016-02-09 Restructure Hardware
    prepare for an TFT only adapter board
    [Cursor-EC60.brd, Cursor-EC60.sch, Debouncer.brd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]
2016-03-07 rework UI
    [Debouncer.sch, EC60_1.sch, TFT-Board.brd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]
2016-03-11 Sülzfleisch in Tüten
    [TFT-Board.brd]
2016-03-13 Fixing the boards
    [Cursor-EC60.brd, Cursor-EC60.sch, Debouncer.brd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]
2016-03-13 final CAM result
    [Debouncer.GBL, Debouncer.GBO, Debouncer.GBP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]
2016-03-14 fixing size issue
    [metaPixel-Controller.GBL, metaPixel-Controller.GBO, metaPixel-Controller.GBP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]
2016-03-31 fixing TFT_LED problem
    [metaPixel-Controller.brd, metaPixel-Controller.sch]
2016-04-05 switches now work
2016-04-05 Tweaking Effects
    - adding macro start on power on
    - endless demo Macro and tweaked animation.
2016-04-09 removing unused boards and files
    [Cursor-EC60.brd, Cursor-EC60.sch, CursorKeypad.brd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]
2016-04-09 renaming an STL and adding a bunch of CAD files
    [Connector.stl, metaPixel-Boxes v28.f3d, metaPixel-Boxes.f3d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]
2016-04-10 tweaking frame rate and adding water effect
2017-12-14 added some warning if module dimensions are not set
    [metaPixel-Controller.brd, metaPixel-Controller.sch]

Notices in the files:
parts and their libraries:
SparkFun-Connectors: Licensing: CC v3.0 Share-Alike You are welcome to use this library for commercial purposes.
